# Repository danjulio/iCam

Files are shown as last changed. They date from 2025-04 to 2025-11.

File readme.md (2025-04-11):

## iCam and iCamMini thermal imaging cameras

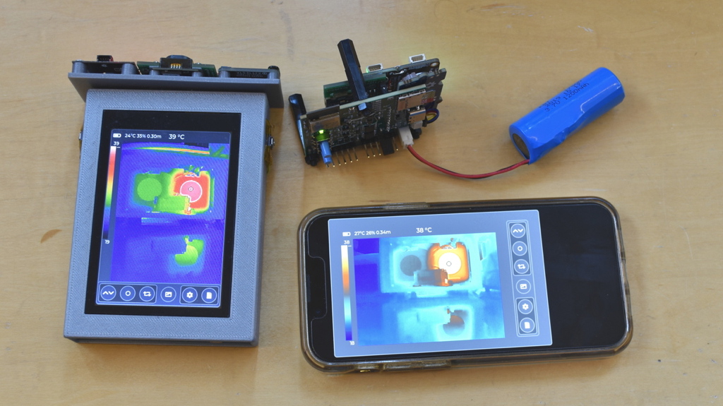
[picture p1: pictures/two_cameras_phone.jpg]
iCam and iCam Mini


This repository contains the design files for my Infiray Tiny1C-based thermal imaging cameras.  It also contains the documentation I have for the Tiny1C module from Infiray.

1. iCam - Handheld camera with local LCD touchscreen based on my ESP32 [gCore](https://github.com/danjulio/gCore) development board and the Tiny1C breakout board in this repository.
2. iCamMini - Portable camera with either web-based access or NTSC/PAL video output based on the iCamCntrl board in this repository and the Tiny1C breakout board.

The cameras share a common code base and feature set.

1. 256 x 192 pixel resolution.
2. Radiometric operation with adjustable emissivity.
3. Support for optional environmental (object distance, temperature and humidity) correction.
4. Adjustable high/low gain for extended temperature detection.
5. Support for calibration against a black body radiator.
6. Ten pseudo-color palettes.
7. Image storage and playback as jpg files on a Micro-SD card.
8. Selectable point and region markers.
9. Scene min/max temperature display.
10. Timelapse operation.
11. Battery-backed real-time clock for time stamping.
12. Rechargeable Li-Ion battery power source (or USB/external power).

tCam display is a local 16bpp 480x320 pixels capacitive touchscreen LCD.

tCamMini display is either via a Wi-Fi connected remote web browser (mobile aware) or analog video output (NTSC or PAL).  Analog video output may be used for long-distance operation, for example mounted on a UAV with video transmission capability.

### GUI
The main user interface screen is shown below.

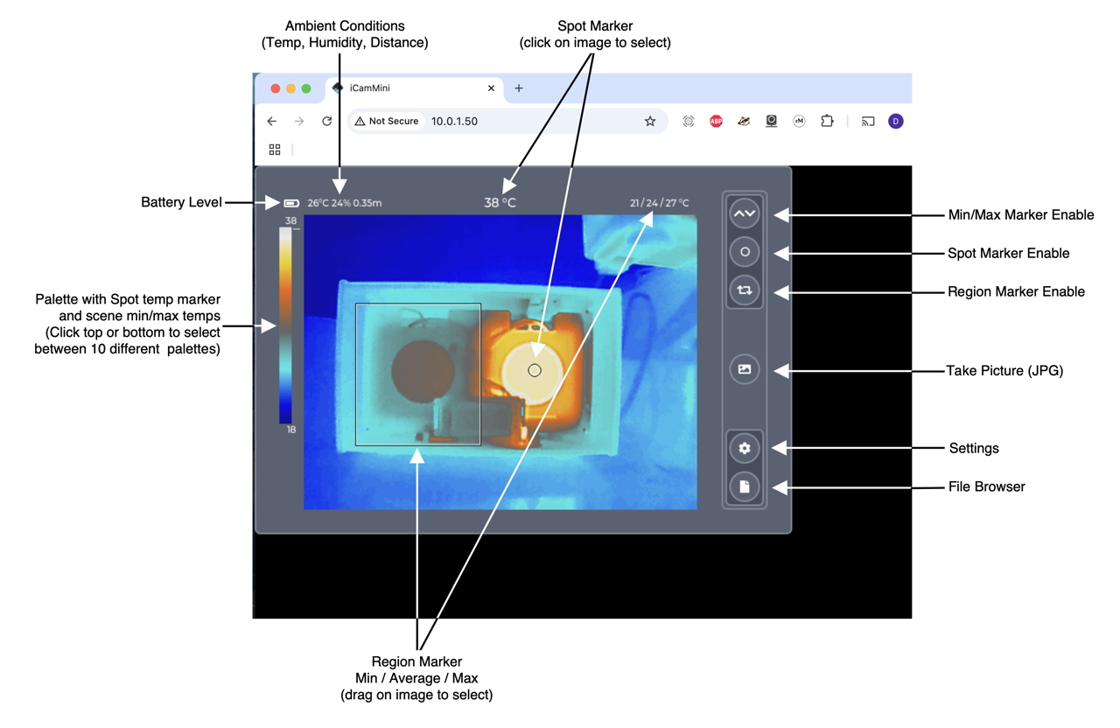
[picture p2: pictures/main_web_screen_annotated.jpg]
Main Screen


iCamMini also generates a simplified display when configured for analog video output.

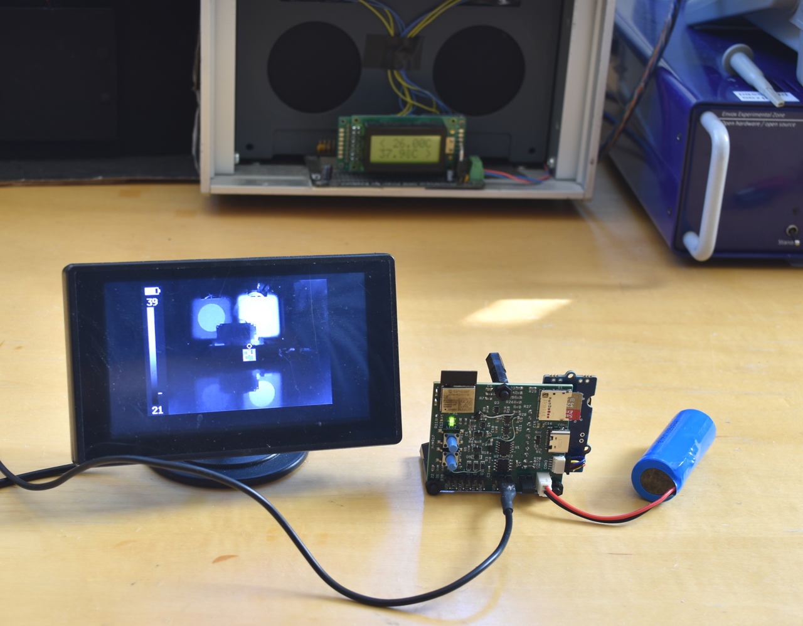
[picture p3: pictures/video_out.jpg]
Video output


Please see the readme in the iCamMini subdirectory for operation of the camera when configured for analog video output.

#### Settings
The settings screen configures the camera.  Most settings are identical on both cameras (for example, iCam does not have a Wi-Fi settings screen, iCamMini does not have a local brightness control).

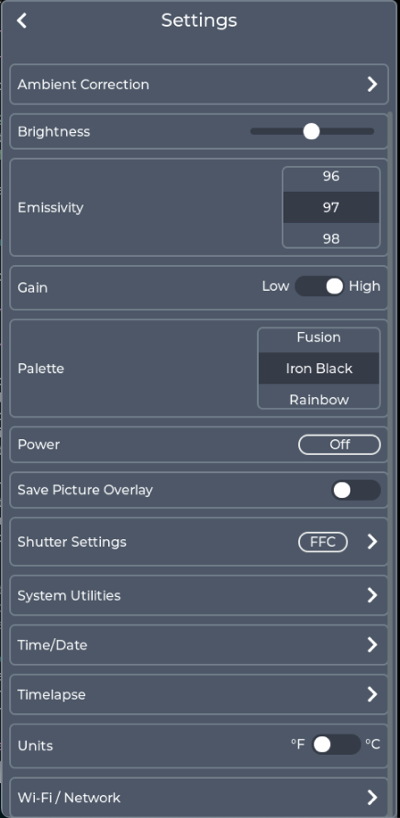
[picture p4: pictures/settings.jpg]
Settings Screen


##### Ambient Correction
Compensation factors for environmental conditions including ambient temperature and distance to object may be applied to improve radiometric temperature accuracy.  Currently humidity correction is not supported.

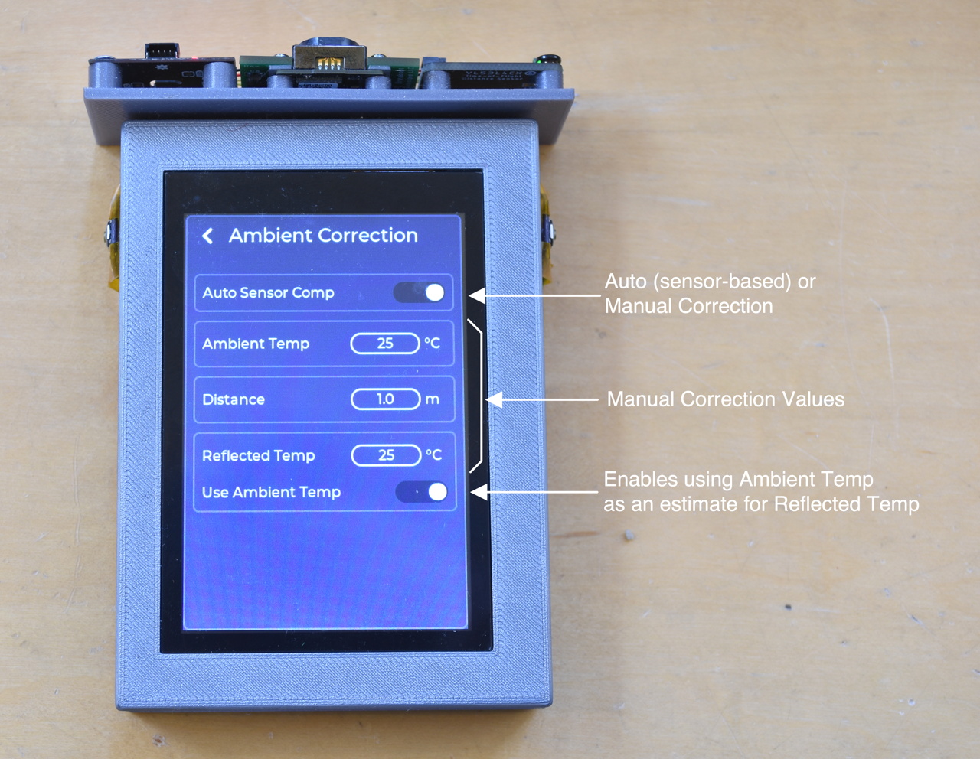
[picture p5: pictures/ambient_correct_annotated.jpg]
Ambient correction


These compensation factors may be configured manually through the Ambient Correction screen or automatically if [AHT20](https://www.adafruit.com/product/4566) Temperature/Humidity sensor and/or [VL53L4CX](https://www.adafruit.com/product/5425) 4M time-off-flight sensors are connected to the camera's I2C interface.  These sensors are automatically detected and applied if enabled in the Ambient Correction screen.

##### Tiny1C Calibration
One- or two-point calibration against a known black body radiator may be performed.

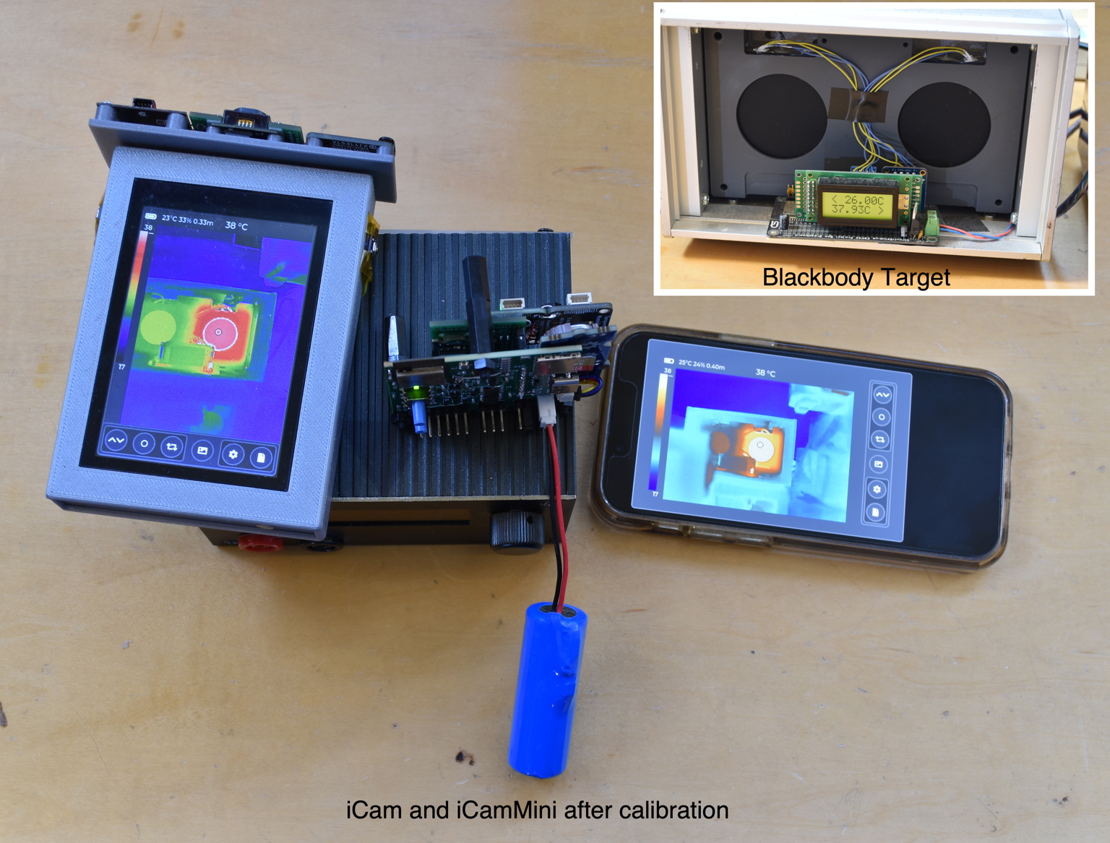
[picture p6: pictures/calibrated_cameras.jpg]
Calibration


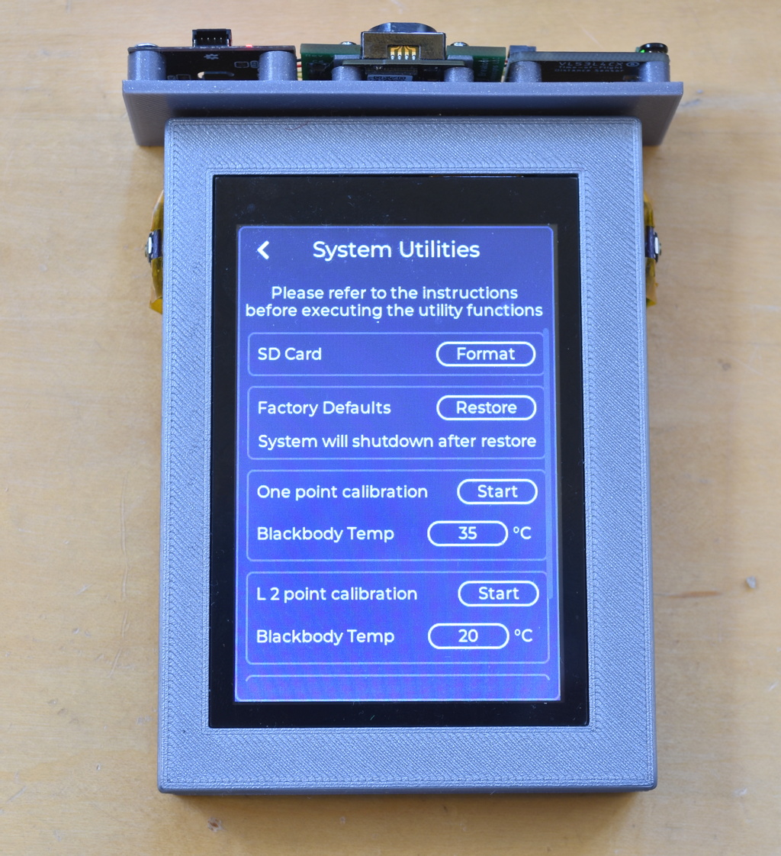
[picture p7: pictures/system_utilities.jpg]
Calibration Utilities


During calibration the camera should be 25 cm from a known black body radiator at a stable temperature.  The black body emissivity should be configured in the Emissivity Settings panel, and gain configured in the Gain Settings panel.

Two-point calibration is more accurate than one-point calibration but requires two widely separated black body temperatures (e.g. 293K and 393K in high gain and 373K and 673K in low gain).

Set the black body radiator temperature and then press ```Start```.  For two-point calibration, perform the ```L 2 point calibration``` and then perform the ```H 2 point calibration```.

##### Shutter configuration
Parameters related to automatic Flat Field Correction using the Tiny1C's built-in shutter are configured using the Shutter Settings screen.

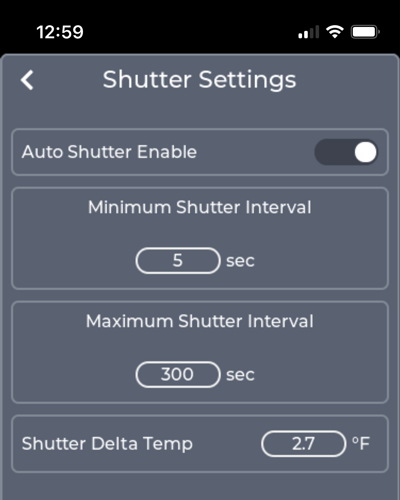
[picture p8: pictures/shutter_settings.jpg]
Shutter settings


##### Time / Date
The camera's clock is set through the Time/Date screen.  The clock is used to time stamp stored images.

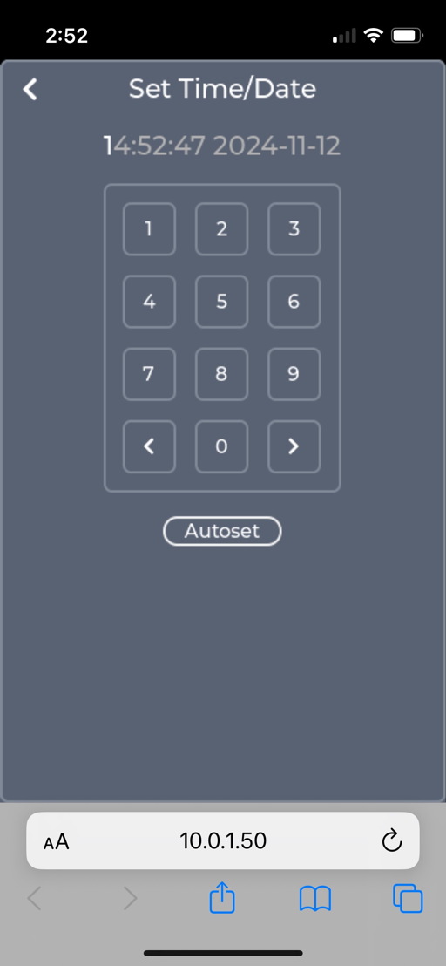
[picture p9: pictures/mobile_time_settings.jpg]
Time/Date screen
.

Pressing the ```Autoset``` button (iCamMini only) sets the camera to the host computer's current time.

##### Timelapse Operation
The camera may be configured to periodically take a picture.  The time between photographs and the number of photographs to take is configurable.

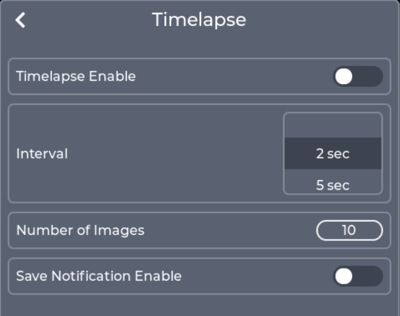
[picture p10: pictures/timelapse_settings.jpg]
Timelapse settings


Enabling Save Notifications will display the image name on the Main screen as it is taken.  The Main screen Take Picture button turns red while timelapse operation is in progress.

#### File Browser
Clicking the Take Picture button on the main screen (or pressing one of the buttons on iCamMini) stores the current image as a jpg file on the Micro-SD card if present.  The File Browser screen allows displaying and deleting image files.

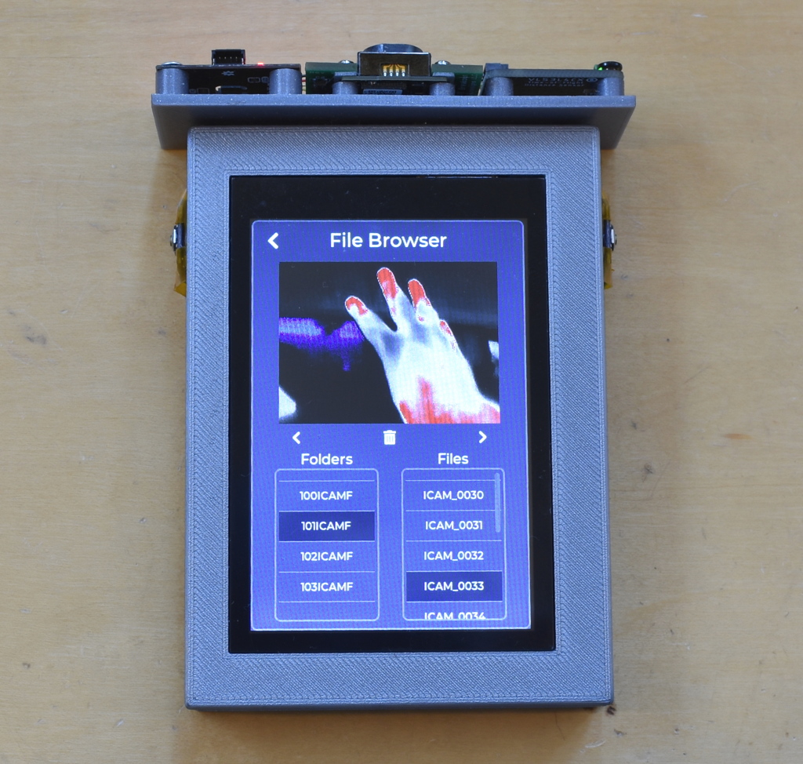
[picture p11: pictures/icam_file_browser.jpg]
File Browser


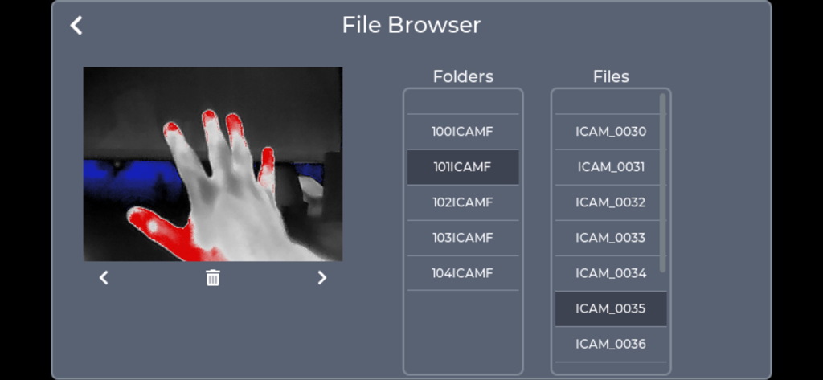
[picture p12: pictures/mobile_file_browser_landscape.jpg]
Landscape File Browser


Note the conversion process to a jpg image takes a few hundred milliseconds.

##### Image Files
Files are stored on the Micro-SD card using a DCIM compatible structure with 100 pictures per folder.

* Folder naming convention: ```nnnICAMF``` where ```nnn``` is a numeric sequence starting at 100.
* File naming convention: ```ICAM_nnnn.JPG``` where ```nnnn``` is a numeric sequence starting at 0001.

Files are 256x192 pixels in size.  An optional overlay of meta-data information can be included when the Save Picture Overlay is enable on the Main Settings screen.

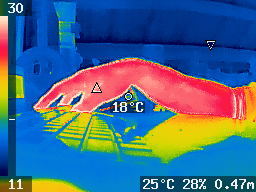
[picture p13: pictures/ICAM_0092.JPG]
Example jpg image


#### iCamMini Wi-Fi operation
When configured for Wi-Fi operation iCamMini is capable of acting as an Access Point (default) or a client connected to an existing Wi-Fi network.

It supports an mDNS responder that allows discovery from a web browser without having to know the IPV4 address.  The mDNS responder recognizes the local URL ```icam.local```.

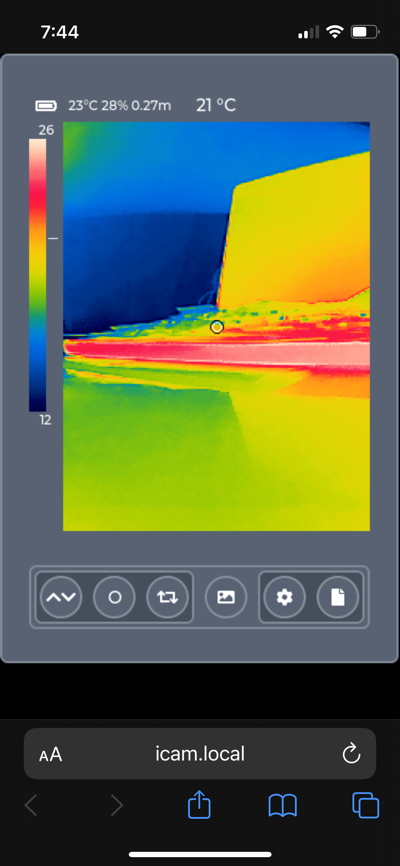
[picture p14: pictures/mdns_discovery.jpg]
mDNS Discovery


The Wi-Fi settings allow configuring the mode as well as an optional static IP address when configured into STA mode.

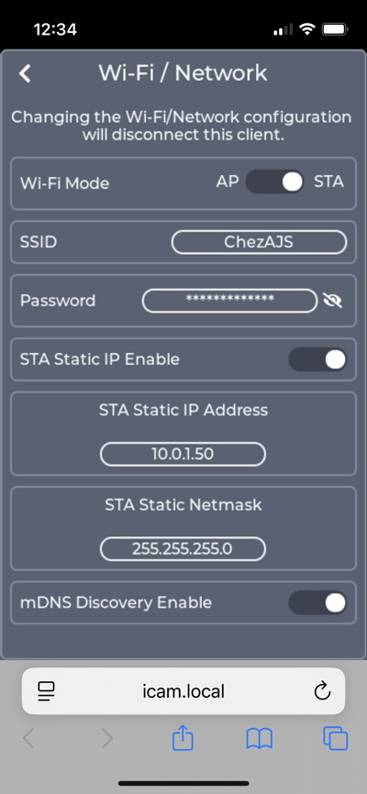
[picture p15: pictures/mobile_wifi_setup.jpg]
Wi-Fi settings


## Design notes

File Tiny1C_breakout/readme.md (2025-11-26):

## Tiny1C Breakout PCB
The Tiny1C Breakout PCB is used by both iCam and iCamMini.  It provides access to the Tiny1C VoSPI and I2C Command interfaces, as well as providing a low noise 5V analog power supply for the imager from a 3.3V input supply.  It provides a header interface for the [VL53L4CX](https://www.adafruit.com/product/5425) 4M time-off-flight sensor so that it can be close and aligned with the Tiny1C.  It also provides access to the Tiny1C diagnostic serial port and three of its GPIO signals (currently unused as far as I can tell).

The pinout basically follows the Flir Lepton breakout board sold by Group Gets.

This directory contains the gerber files as well as schematic documentation and a centroid file.  Parts can be found at my [Mouser shared BOM](https://www.mouser.com/Tools/Project/Share?AccessID=772c639990).

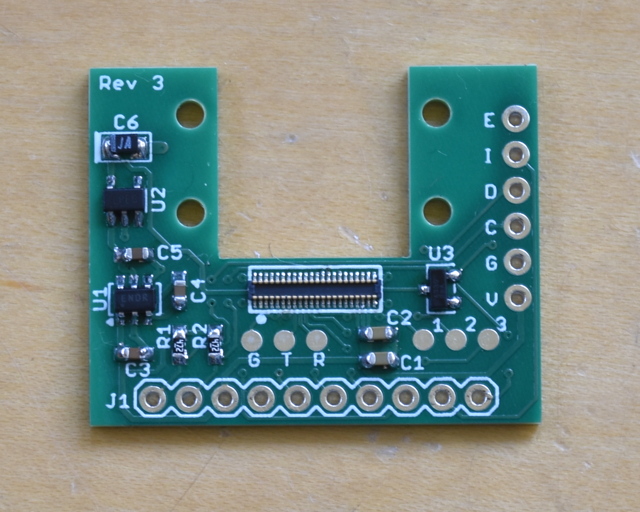
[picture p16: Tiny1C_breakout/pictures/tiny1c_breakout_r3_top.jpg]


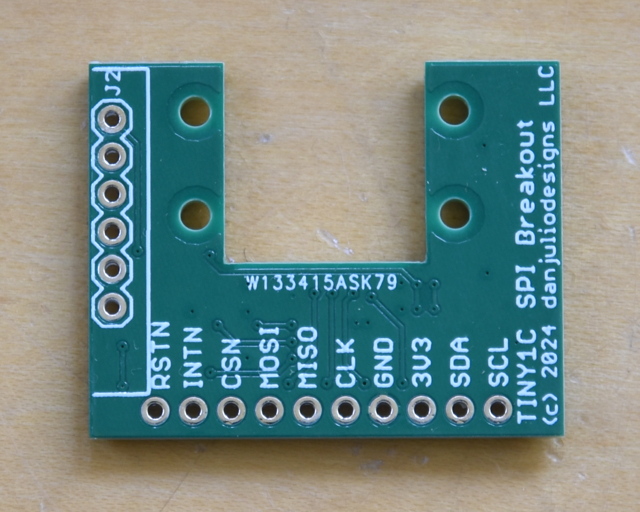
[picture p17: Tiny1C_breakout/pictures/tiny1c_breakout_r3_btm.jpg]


### Gerber Files

* 2 layer board
* 1.25" x 1.0"
* 1.6 mm thickness

| File | Description |
| --- | --- |
| tiny1c_breakout.GBL | Bottom Copper |
| tiny1c_breakout.GBO | Bottom Silkscreen |
| tiny1c_breakout.GBS | Bottom Soldermask |
| tiny1c_breakout.GML | Mill (outline) |
| tiny1c_breakout.GTL | Top Copper |
| tiny1c_breakout.GTO | Top Silkscreen |
| tiny1c_breakout.GTS | Top Soldermask |
| tiny1c_breakout.TXT | Drill |

### Board Connections

| Pin | Description |
| --- | --- |
| SCL | I2C clock signal to Tiny1C and VL53L4CX header |
| SDA | I2C data signal to Tiny1C and VL53L4CX header |
| 3V3 | 3.3V power supply for Tiny1C and VL53L4CX header.  Should be capable of 500 mA. |
| GND | Ground |
| MISO | SPI Data output from Tiny1C |
| MOSI | SPI Data input to Tiny1C |
| CSN | SPI active low chip select for Tiny1C |
| INTN | Active low interrupt from VL53L4CX header |
| RSTN | Active low reset input/output to Tiny1C and VL53L4CX.  See note below. |

The breakout board contains a power-on reset generator that pulls this signal low.  It may also be pulled low using an open-drain output on another controller.  The Tiny1C includes a built-in pull-up resistor on this line.

### Tiny1C Serial Port Connections

| Pad | Description |
| --- | --- |
| G | Ground |
| T | Tiny1C TX |
| R | Tiny1C RX |

### Tiny1C GPIO Port Connections

| Header Pin | Description |
| --- | --- |
| V | 3.3V Power input |
| G | Ground |
| C | I2C SCL |
| D | I2C SDA |
| I | GPIO Interrupt |
| E | Active low shutdown (used as reset input) |

## VL53L4CX Support

VL53L4CX Breakout board may be mounted on either side of the Tiny1C breakout board depending on your enclosure needs.  I used short pieces of cut wire soldered on both sides to hold the boards close together.  The I2C pull-up resistors may be left in place.

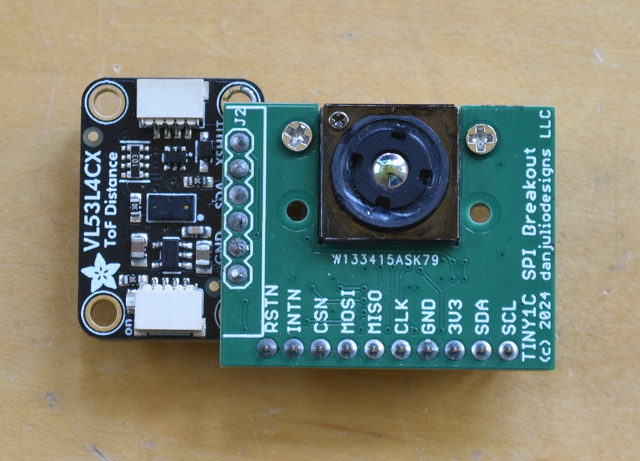
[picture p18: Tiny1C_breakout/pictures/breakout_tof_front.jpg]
Breakout with TOF Front


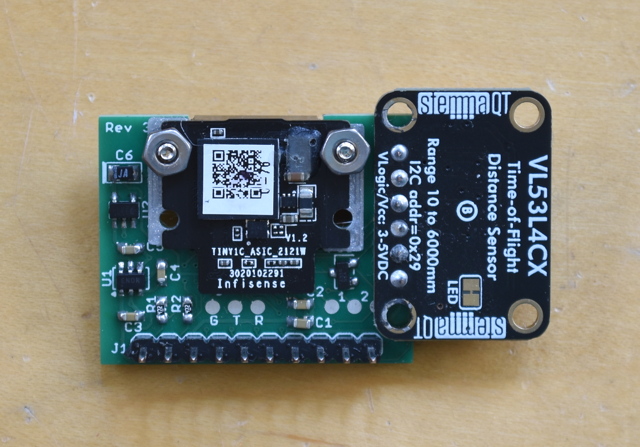
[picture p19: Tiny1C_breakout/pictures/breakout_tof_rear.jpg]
Breakout with TOF Rear


The Qwiic connector can be used to attach the AHT20 Temperature/Humidity sensor using a short Qwiic cable.  You want this sensor to be removed from any heat generating components, ideally only sampling the air around the camera.

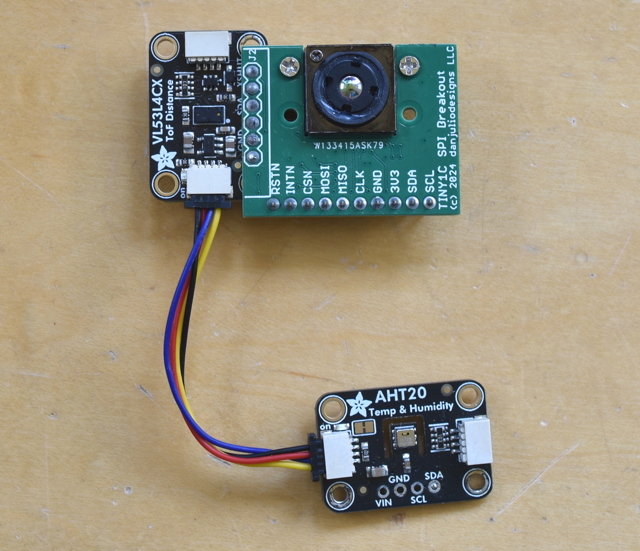
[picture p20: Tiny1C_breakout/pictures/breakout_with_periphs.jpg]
Breakout with TOF and Temp/Humidity Sensors


## Spacer and Tiny1C Mounting

The ```spacer``` subdirectory contains an OpenSCAD design (and resultant STL file) for a spacer that goes between the Tiny1C and the breakout board.  Two of these should be printed on a 3D printer.  Then a set of small screws can be used to secure the Tiny1C to the board.

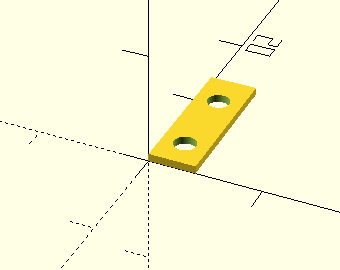
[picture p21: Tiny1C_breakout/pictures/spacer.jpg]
Spacer


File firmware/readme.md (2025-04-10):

## iCam Firmware
The firmware (```iCamCntrl```) in this directory runs on both iCam (gCore platform) and iCamMini (iCamCntrl platform) using the Espressif IDF.  It must be compiled separately for each platform.  Differences between the platforms are managed by conditionally compiled code.  A portion of this firmware for the iCamMini is also built using emscripten.  Much of the source code (the GUI code itself and the LVGL graphics library) are shared between the ESP32 and emscripten builds (see architecture diagrams below).

### Prerequisites
This firmware requires the following development environments.

1. [Espressif IDF v5.3](https://docs.espressif.com/projects/esp-idf/en/release-v5.3/esp32/index.html)
2. [Emscripten](https://emscripten.org/) - I build with SDK 3.1.64 but later versions should work too.  I also had to install SDL2 (on mac: ```brew install sdl2```).

I build using Mac OS X but this project should be buildable on Linux and Windows platforms as well, perhaps with some changes to shell commands.

### Building for iCam
Building firmware for iCam (gCore) is a straight-forward ESP32 IDF build.

#### Setup
1. Change to the ```firmware``` subdirectory
2. Source (run) the Espressif ```export.sh``` file and setup the ```IDF_PATH``` environment variable.
3. Source (run) the ```set_platform.sh``` script with the argument ```icam```.

``` ./set_platform.sh icam```

#### Build
Build the project using the Espressif tools

```idf.py build```

#### Program

##### Using IDF tools
Plug gCore into your computer and turn it on so that its serial port may be recognized and enumerated by the operating system.  Make a note of the serial port name (for example on OS X it is ```/dev/cu.SLAB_USBtoUART```).

```idf.py -p [SERIAL PORT] -b 921600 flash```

where SERIAL PORT is the serial port associated with gCore.

##### Using the Windows-based Espressif programming tool
The precompiled firmware files found in the ```iCam/precompiled``` directory may be downloaded without having to build them using the Windows-based Espressif Flash Download tool that can be found [here](https://www.espressif.com/en/support/download/other-tools).

The various files are loaded in flash memory as follows.

| Binary File | Flash Location |
| --- | --- |
| bootloader.bin | 0x1000 |
| iCamCntrl.bin | 0x10000 |
| partion-table.bin | 0x8000 |
| ota\_data\_initial.bin | 0xd000 |
| storage.bin | 0xb10000 |

#### Serial Diagnostic data

The firmware logs various events to gCore's USB serial port.  This may be viewed by connecting the Espressif serial monitor as shown below.

```idf.py -p [SERIAL PORT] monitor```

### Building for iCamMini
Building firmware for iCamMini (iCamCntrl hardware) is a two-step process.

1. Build the HTML page that the camera sends to the browser using emscripten, compress it and copy it to the Espressif project.
2. Build the Espressif project and load the combined binary into the camera.

#### Emscripten build
Build the emscripten portion before building and programming the ESP32 portion.  This only needs to be done initially or when any part of the emscripten source changes.

1. One time only: change directory to the ```emscripten``` subdirectory and create a ```build``` directory there.
2. Change directory to ```emscripten/build``` subdirectory in a shell dedicated to building the emscripten portion of the firmware.
3. Source the emscripten ```emsdk_env.sh``` file to configure the emscripten environment.
4. First time and only when you add new source files to the emscripten build: run the command ```emcmake cmake ..```
5. Build the emscripten code: ```emmake make -j4```
6. Compress the resultant html file: ```gzip index.html```
7. Move the compressed file into the ESP32 build area: ```mv index.html.gz ../../components/esp32_web```

Steps 5-7 are performed each time a change is made to the existing firmware.  Perform step 4 when the file structure changes.

#### ESP32 build
I build the ESP32 portion using another shell window.  It is done after making any emscripten changes.  The compressed HTML file must be built and stored in the ```components/esp32_web``` subdirectory.

1. Change directory to the ```firmware``` subdirectory.
2. Configure the project to build for iCamMini: ``` ./set_platform.sh icam_mini```
3. Build the project using the Espressif tools:```idf.py build```

#### Program

##### Using IDF tools
Plug the iCamCntrl board into your computer and press and hold the power button so that its serial port may be recognized and enumerated by the operating system.  Make a note of the serial port name (for example on OS X it is something like ```/dev/cu.wchusbserial110```).

```idf.py -p [SERIAL PORT] -b 921600 flash```

where SERIAL PORT is the serial port associated with iCamCntrl.

##### Note about iCamCntrl power
You must continue to hold the power button on during programming because the hardware implements a soft power control in firmware.  When firmware is not running then it cannot drive a GPIO output that holds power enabled.  You may release the power button after programming is finished.

When programming is finished then press the power button and hold until the status LED lights.   At this point the firmware is driving the power hold signal.

##### Using the Windows-based Espressif programming tool
The precompiled firmware files found in the ```iCamMini/precompiled``` directory may be downloaded without having to build them using the Windows-based Espressif Flash Download tool that can be found [here](https://www.espressif.com/en/support/download/other-tools).

The various files are loaded in flash memory as follows.

| Binary File | Flash Location |
| --- | --- |
| bootloader.bin | 0x1000 |
| iCamCntrl.bin | 0x10000 |
| partion-table.bin | 0x8000 |
| ota\_data\_initial.bin | 0xd000 |
| storage.bin | 0x710000 |

#### Serial Diagnostic data

The firmware logs various events to iCamCntrl's USB serial port.  This may be viewed by connecting the Espressif serial monitor as shown below.

```idf.py -p [SERIAL PORT] monitor```

### Firmware Architecture
Most of the code is shared between both platforms.  Aside from platform-specific functionality (and analog video output) the main difference is in where the LVGL-based GUI runs.  In order to support this architecture the GUI display is separated from the camera application code by a SET/GET/RESPONSE command interface.  These commands are used to get and update state on both sides of the interface.  In iCam they become direct function calls between domains and in iCamMini they are serialized and deserialized across a websocket interface.

![iCam Firmware Architecture](pictures/icam_fw_arch.jpg)

![iCamMini Firmware Architecture](pictures/icam_mini_fw_arch.jpg)

The command interface is not used when iCamMini is configured for video output.

![iCamMini Firmware Architecture with Video output](pictures/icam_mini_vid_fw_arch.jpg)

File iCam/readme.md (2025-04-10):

## iCam Prototype
I call this a prototype because I'd like to design a better enclosure but the camera itself is functional.

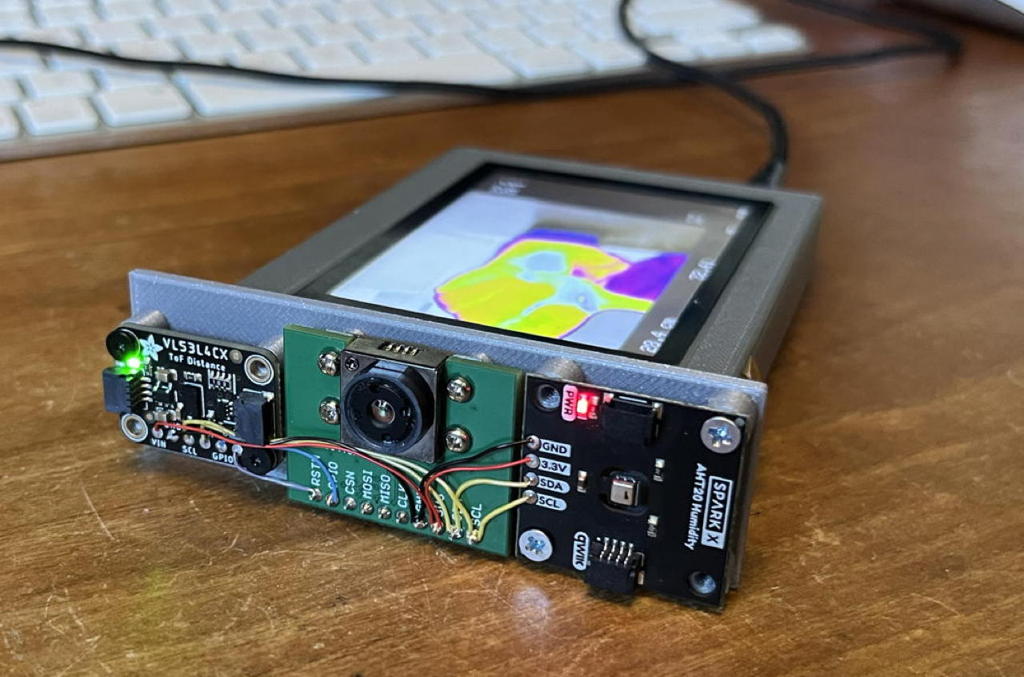
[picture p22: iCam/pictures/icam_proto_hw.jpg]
iCam Prototype Hardware


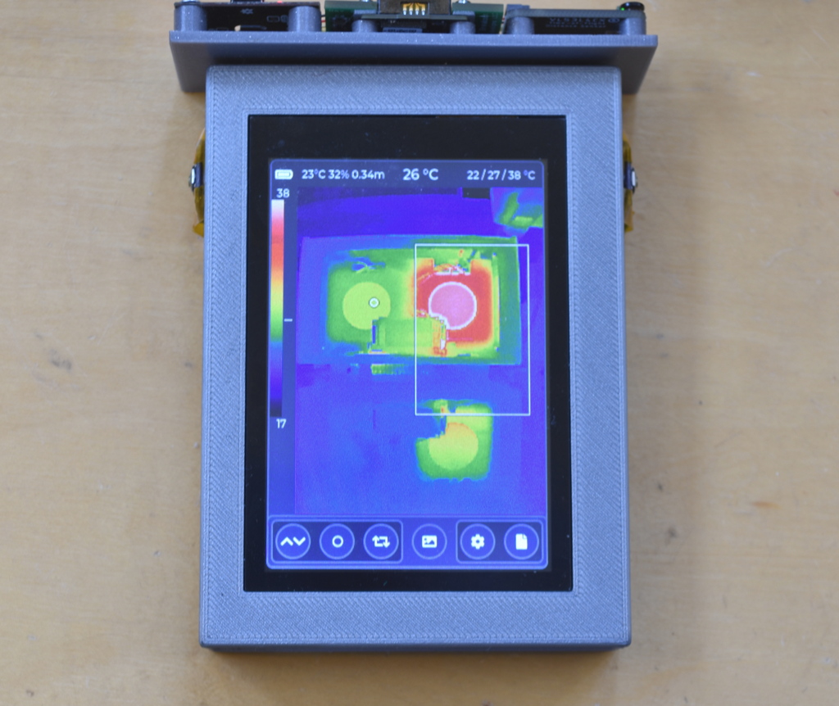
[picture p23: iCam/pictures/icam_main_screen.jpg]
iCam Main Screen


Instructions for programming the precompiled firmware may be found in the ```firmware``` directory.

### Hardware Architecture
The hardware consists of a [gCore](https://github.com/danjulio/gCore) development board with Tiny1C, VL53L4CX and AHT20 breakout boards.

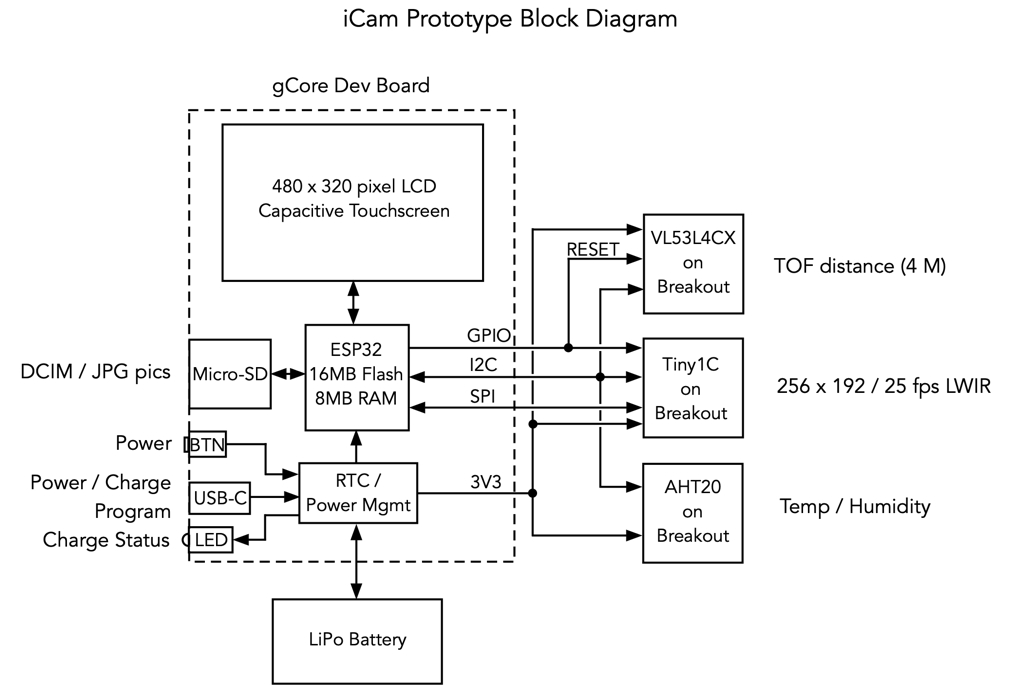
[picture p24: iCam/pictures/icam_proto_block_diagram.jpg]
iCam Hardware Architecture


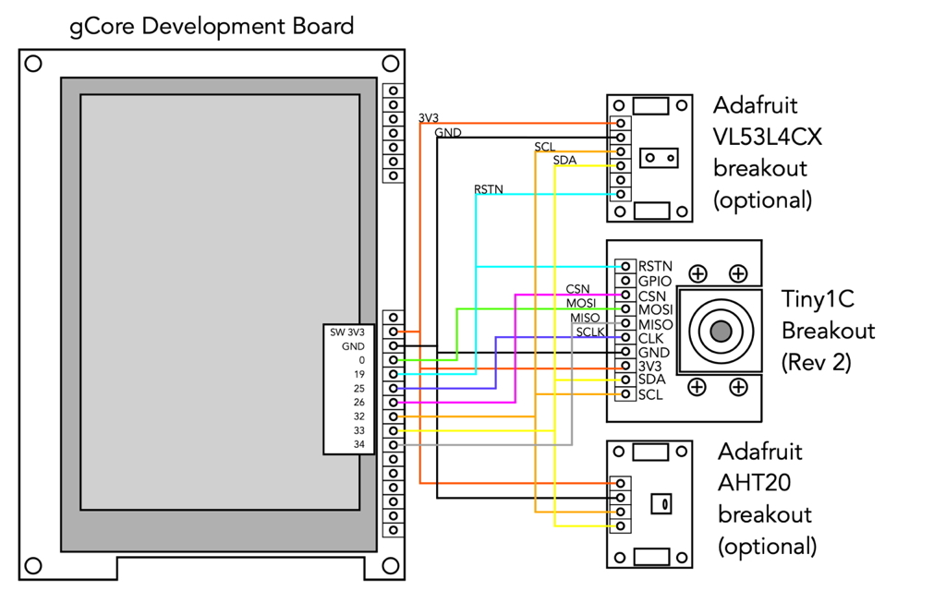
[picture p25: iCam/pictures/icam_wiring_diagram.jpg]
iCam Hardware Diagram


Note that the reset signal goes to both the Tiny1C and VL53L4CX boards.  This is necessary as the firmware resets the hardware before configuring it and the VL53L4CX will malfunction if you attempt to reconfigure it after it has been running without a reset.

### Prototype Enclosure
The enclosure consists of two 3D printed parts, the gCore enclosure (which you can find at the gCore repo) and a sensor mount that's double-sticky tape attached to the gCore enclosure.

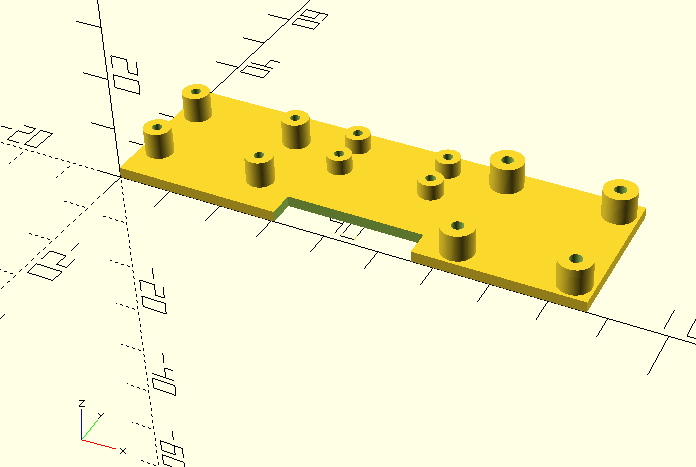
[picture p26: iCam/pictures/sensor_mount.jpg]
Sensor Mount render


The OpenSCAD design and resultant STL file for the sensor mount may be found in the ```sensor_mount``` subdirectory.  Note that for this prototype I used a Sparkfun AHT20 breakout board so the mount will have to be redesigned to use the Adafruit version (just copy the VL53L4CX portion over).

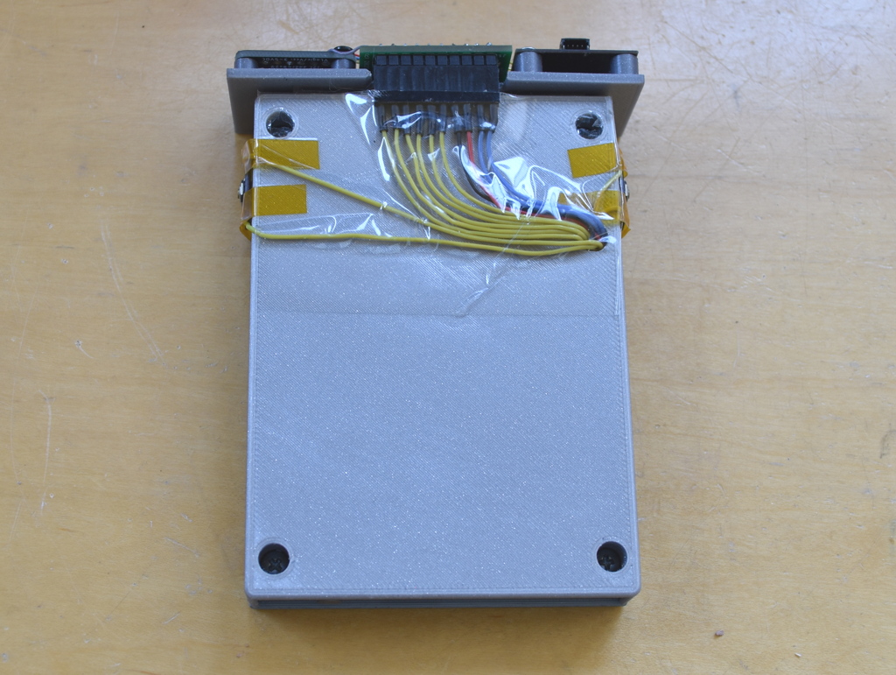
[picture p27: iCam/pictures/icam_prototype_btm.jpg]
Sensor Mount attachment


Note that I wired two buttons on this prototype but they are currently unused by the firmware.

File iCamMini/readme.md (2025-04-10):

## iCamMini
iCamMini is a small, battery powered, thermal imaging camera with two different output modes.  It can communicate with a remote web browser over Wi-Fi or it can output an analog video output with either NTSC or PAL timing.

It is comprised of a iCamCntrl main board and Tiny1C Breakout board.  Optionally a VL53L4CX and/or AHT20 breakout board may be added sensing environmental conditions to improve the radiometric accuracy of the camera.

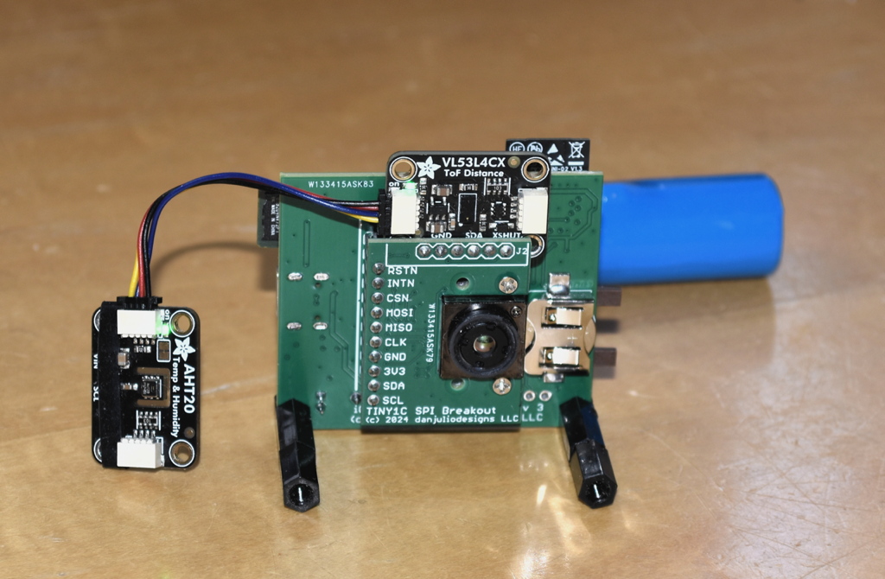
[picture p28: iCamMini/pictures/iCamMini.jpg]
iCamMini hardware


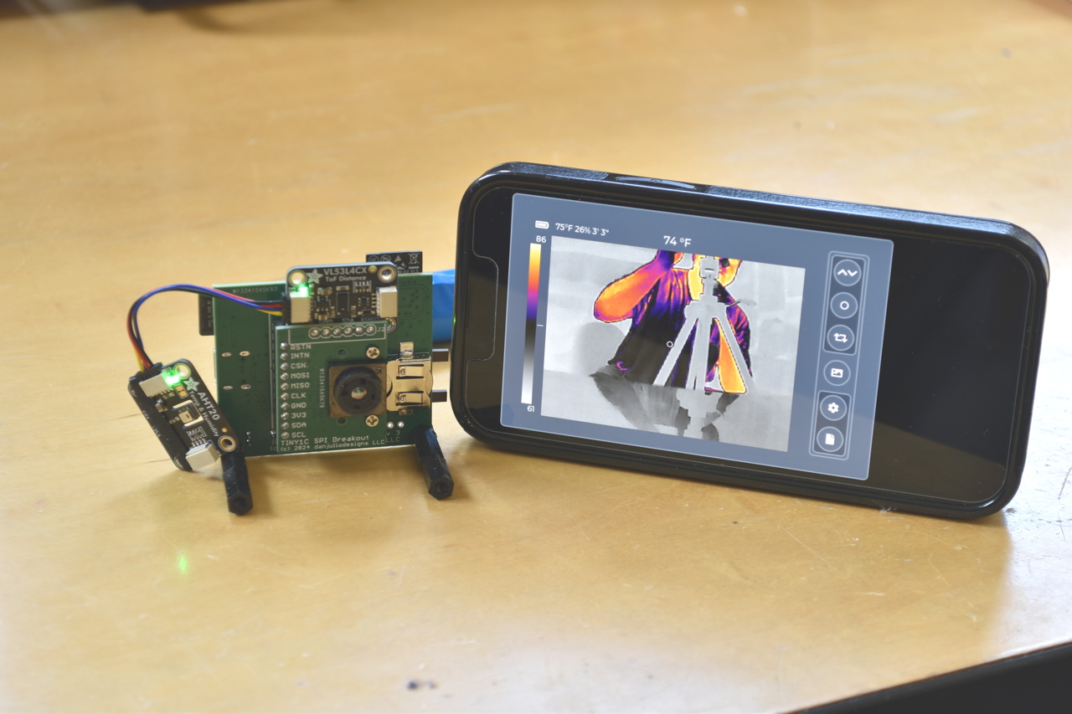
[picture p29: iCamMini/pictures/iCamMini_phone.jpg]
iCamMini with iPhone


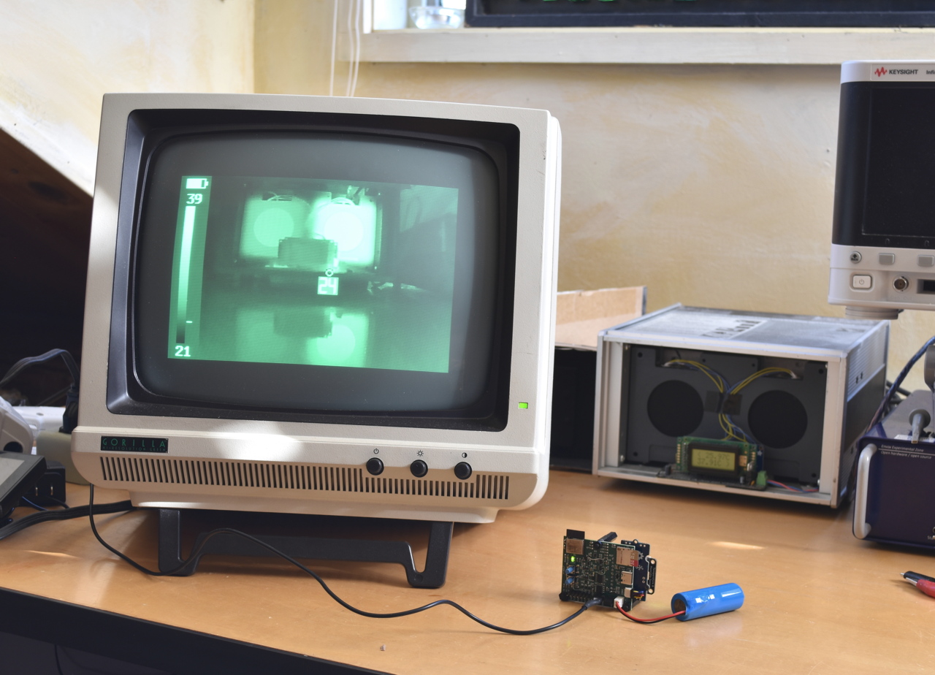
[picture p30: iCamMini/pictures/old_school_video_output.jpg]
iCamMini with old-school analog monitor


The iCamCntrl hardware is documented in the ```iCamCntrl_board``` subdirectory.

### Battery
iCamMini can operate with or without a 3.7V Li-Ion battery.  The Li-Ion battery charger provides up to 500 mA of charge current.  The battery should be 2500 mA or less.  The camera typically operates between 200-300 mA (with bursts when the Tiny1C performs a flat-field correction).

#### RTC Battery
The real-time clock is kept powered when the camera is off using a CR1225 3V Lithium coin cell.

### Mode Selection
The output mode is selected at boot using the MODE jumper.  It cannot be changed once the camera is running.

| Jumper Position | Mode |
| --- | --- |
| In | Wi-Fi/Web Browser mode |
| Out | Analog output mode |

### Board Controls
The board contains two push buttons (PB1, PB2) and two LEDs (LED1, LED2).  LED1 is a blue LED.  LED2 is a red/green LED capable of three colors (Red, Green, Orange/Yello).

PB1 is always used to turn the board on or off.  Hold PB1 pressed until LED2 lights.  Then you can release it.  To turn the camera off, press and hold the button for more than three seconds (long-press).  LED2 will turn off then you can release the button.

LED1 is lit when the battery is charging.

LED2 is initially red.  It switches to another, mode-dependent color, when the camera has successfully booted (passed all self-tests and configured all peripherals).  It will blink red if any errors are detected, followed by a short period where it is off.  The number of blinks indicate the failing function. 

| Blinks | Fault Type |
| --- | --- |
| 1 | ESP32 core initialization failed |
| 2 | ESP32 peripheral initialization failed |
| 3 | ESP32 static memory allocation failed |
| 4 | Tiny1C CCI initialization failed |
| 5 | Tiny1C VoSPI communication failed |
| 6 | Tiny1C video stream sync failed |
| 7 | Video output initialization failed |
| 8 | Web Server failure |

LED2 also briefly blinks whenever a picture is taken and stored on the Micro-SD card.

The remaining functionality of the buttons and LED2 depends on what output mode the camera is running. 

### Wi-Fi / Web Browser Mode
LED2 indicates connectivity mode.

| LED2 | Meaning |
| --- | --- |
| Fast Blinking Orange | Wi-Fi Reset |
| Slow Blinking Orange | AP Mode: No device connected |
| | STA Mode: Not connected to AP |
| Solid Orange | AP Mode: Device connected |
| | STA Mode: Connected to AP |
| Solid Green | Client connected (web browser connected) |

#### Button 1

| Press Type | Function |
| --- | --- |
| Short Press | Take Picture when not in settings mode.  Select next parameter value when in settings mode. |
| Long Press | Turn camera off |

#### Button 2

| Press Type | Function |
| --- | --- |
| Short Press | No function. |
| Long Press | Wifi Reset back to default AP settings. |

### Video Output Mode

LED2 turns from red to green to indicate the camera has booted successfully (passed all self-tests and configured all peripherals).

#### Button 1

| Press Type | Function |
| --- | --- |
| Short Press | Take Picture when not in settings mode.  Select next parameter value when in settings mode. |
| Long Press | Turn camera off |

#### Button 2

| Press Type | Function |
| --- | --- |
| Short Press | No function when not in settings mode.  Select next parameter when in settings mode. |
| Long Press | Enter/Exit settings mode. |

#### Video Output Mode Settings

Camera parameters are changed in video output mode by entering settings mode (Button 2 long press).  Short press Button 1 to select among parameter values.  Short press Button 2 to select next parameter.  Long press Button 2 to exit settings mode.

The current parameter and value is displayed on the video output screen.

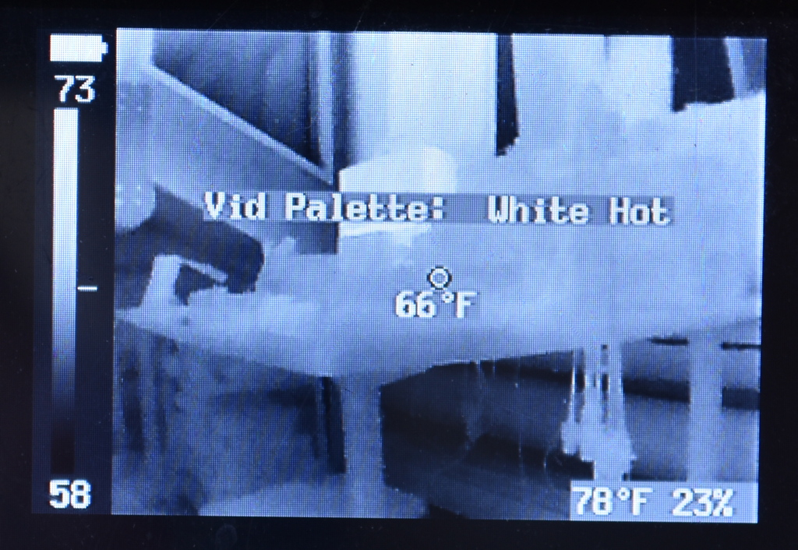
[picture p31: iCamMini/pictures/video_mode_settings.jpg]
Video Mode Settings display


| Parameter | Description |
| --- | --- |
| Vid Palette | Selects between White-hot and Black-hot video output palettes. |
| Spot | Sets Spot (centered) temperature display on or off. |
| Min/Max Markers | Sets minimum and maximum temperature markers on or off. |
| FFC | Triggers a flat-field correction in the Tiny1C. |
| Brightness | Sets the Tiny1C video pipeline output brightness. |
| Emissivity | Sets the Tiny1C Emissivity between a set of pre-defined values. |
| Gain | Sets the Tiny1C to Low or High gain. |
| Env Correct | Sets environmental correction on or off.  Note that use of sensors and/or pre-defined values is configured via the control panel in Wi-Fi mode. |  
| Save Overlay | Sets the metadata information display on saved images on or off. |
| Save Palette | Selects one of the ten pseudo-color palettes to use when saving images. |
| Timelapse | Sets timelapse mode on or off.  When on, pressing the Take Picture button starts the timelapse sequence. |
| Timelapse Interval | Sets the interval between timelapse photos from a predefined set of intervals. |
| Timelapse Images | Sets the number of timelapse photos to take from a predefined set of pictures. |
| Tmelapse Notify | Sets the notification of each timelapse picture taken on the video output screen on or off. |
| Units | Selects between Metric (°C) and Imperial (°F) display units. |
| Video | Selects between NTSC and PAL video timing. |

### Video Output
Video output uses the ESP32 8-bit DAC so it is not a perfect display.  DAC codes are allocated as follows.

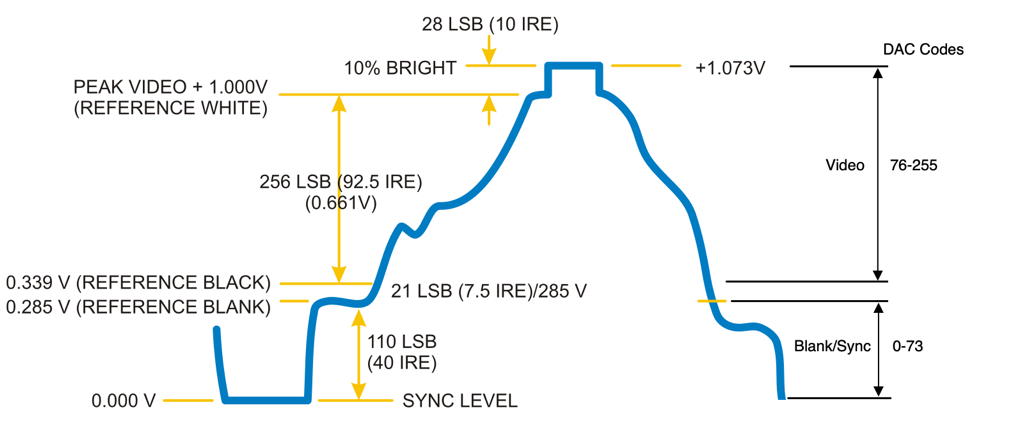
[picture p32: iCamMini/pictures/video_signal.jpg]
Video DAC waveform


The DAC also exhibits some output switch noise that manifests in a sparkling noise overlaying the image.

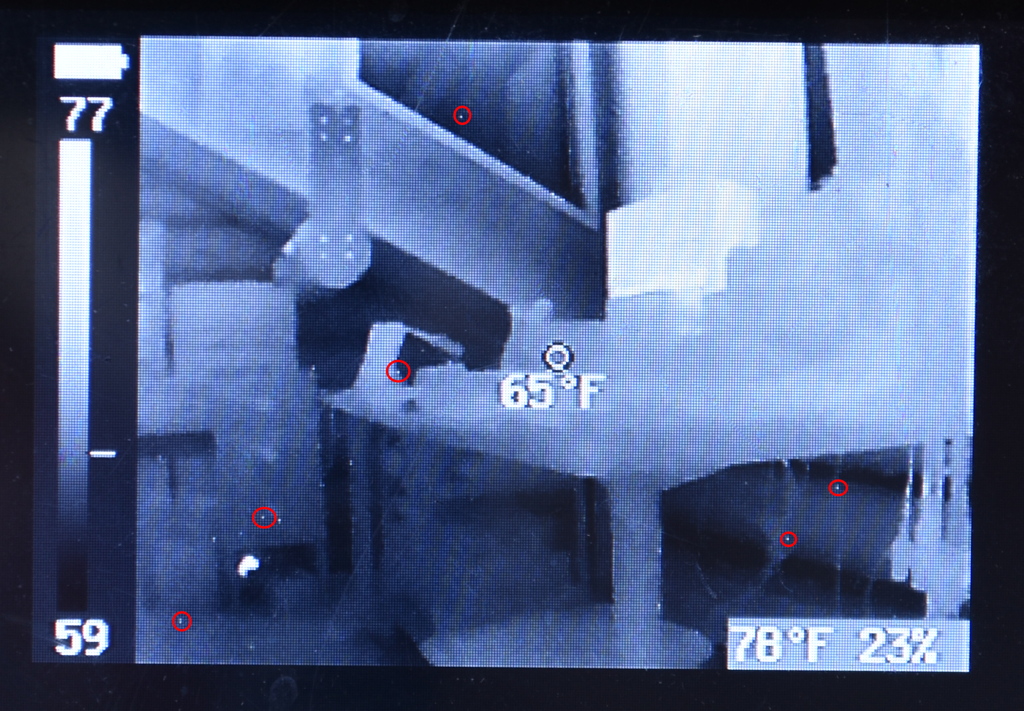
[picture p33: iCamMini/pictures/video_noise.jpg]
Video DAC noise


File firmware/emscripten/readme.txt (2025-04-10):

get_em              [runs [PATH]/emscripten/emsdk/emsdk_env.sh]
cd build
emcmake cmake ..    [first time or when files are added or have been deleted]
emmake make -j4
gzip index.html
mv index.html.gz ../../components/esp32_web

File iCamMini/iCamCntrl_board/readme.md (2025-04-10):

## iCamCntrl PCB
The iCamCntrl PCB forms the core of iCamMini.  It contains the following main subsystems.

1. ESP32-PICO-MINI-02 with 8 MB Flash and 2 MB PSRAM.
2. CH340K based USB UART and USB-C connector for programming and diagnostic output.
3. TP4056 Li-Ion battery charger.
4. Soft power control switching circuitry.
5. Micro-SD card (SPI Interface).
6. PCF85063ATT battery-backed RTC.
7. OPA361 video amplifier and driver, 75 ohm video output.
8. Serial interface with flow control (currently unused).
9. Separate 3.3V power supply for Tiny1C breakout for added noise reduction when generating the Tiny1C 5V analog supply.

It has a flexible power input sources.

1. USB Power (charges battery).
2. 3.7 Volt Li-Ion battery with Sparkfun/Adafruit connector.
3. 5V in on video port (for example may be used for a 3-wire connection on a drone).
4. 5V in on serial port (for example may be used when connected to a UAV controller).

All inputs are diode-isolated.

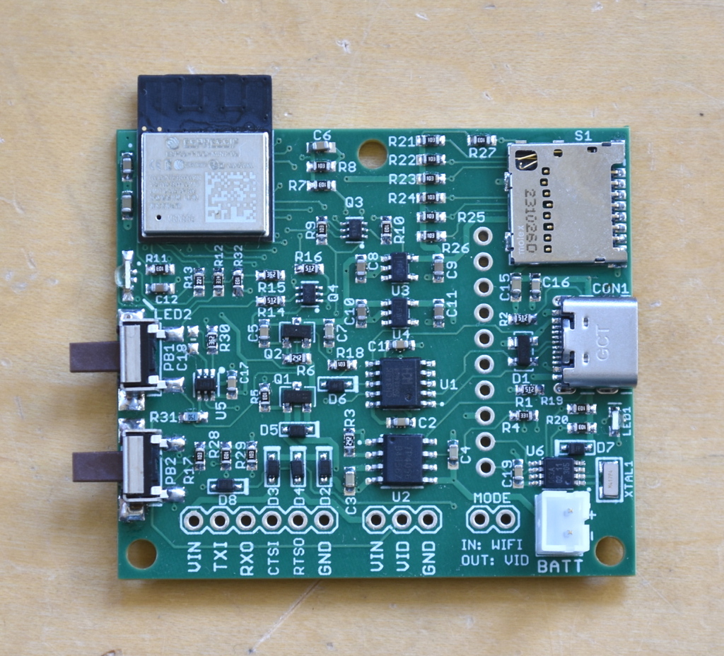
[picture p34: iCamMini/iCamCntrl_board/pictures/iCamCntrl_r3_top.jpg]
iCamCntrl Top


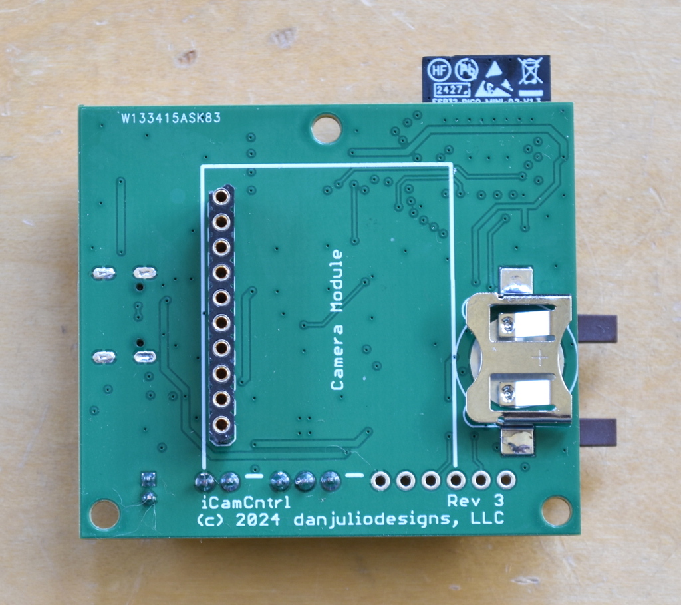
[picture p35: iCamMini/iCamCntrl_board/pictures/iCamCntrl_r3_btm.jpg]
iCamCntrl Bottom


### PCB
* 4 layer board
* 2.0" x 1.75"
* 1.6 mm thickness

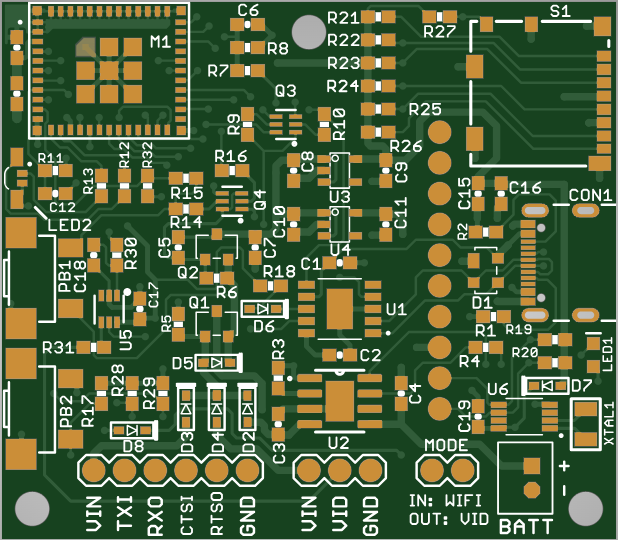
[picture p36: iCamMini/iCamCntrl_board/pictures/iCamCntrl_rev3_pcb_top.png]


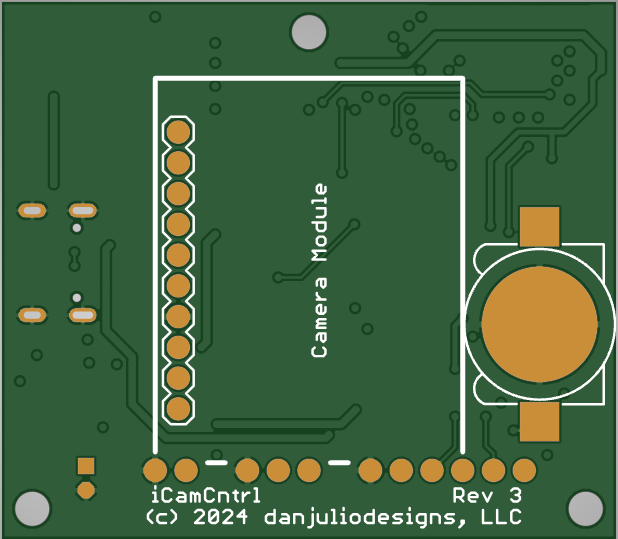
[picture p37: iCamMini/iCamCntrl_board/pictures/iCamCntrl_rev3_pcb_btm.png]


### Gerber Files

| File | Description |
| --- | --- |
| iCamCntrl.GBL | Bottom Copper (layer 4) |
| iCamCntrl.GBO | Bottom Silkscreen |
| iCamCntrl.GBS | Bottom Soldermask |
| iCamCntrl.GL3 | Internal Copper (layer 3) |
| iCamCntrl.GL2 | Internal Copper (layer 2) |
| iCamCntrl.GML | Mill (outline) |
| iCamCntrl.GTL | Top Copper (layer 1) |
| iCamCntrl.GTO | Top Silkscreen |
| iCamCntrl.GTS | Top Soldermask |
| iCamCntrl.TXT | Drill |

### Soft Power Control
Soft Power Control is implemented using a high-side P-Channel MOSFET transistor.  It is enabled when PB1 is pressed.  Then firmware running on the ESP32 must drive the PWR\_HLD signal before the button is released to hold power.  This allows the ESP32 to shut power off by de-asserting PWR\_HLD.  The firmware lights the LED immediately after asserting PWR_HLD at boot as a prompt to the user that they can release the button.  However releasing the button before the ESP32 will result in the board powering down.

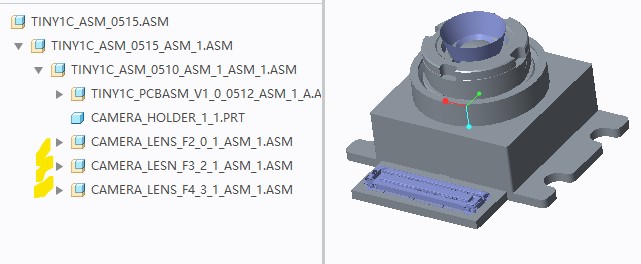
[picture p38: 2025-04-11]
Tiny1C_documentation/mechanical/3D_asm_notes.jpg

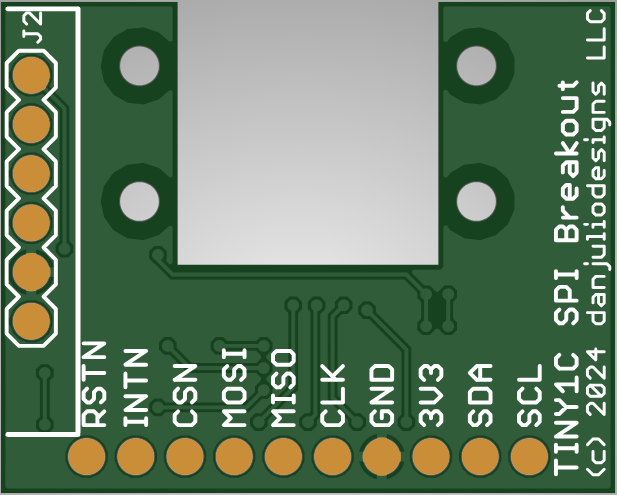
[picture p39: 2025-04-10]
Tiny1C_breakout/pictures/Tiny1C_breakout_rev3_pcb_btm.png

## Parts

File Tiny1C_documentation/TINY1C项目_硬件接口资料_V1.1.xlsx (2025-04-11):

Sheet: Information
TINY1C Module Hardware Interface Brief Introduce
No. | 内容 | Information | Notes
1 | PCBA PN | 2030108356 | PCBA Associated
2 | PCBA Description | 硬质PCBA；TINY1C_ASIC_BOARD_V1_2_1_PCBA
3 | Designer | 姚鹏
4 | Confimed Time | 20211021
5 | Functional Block Diagram | Functional Block Diagram'!A1
6 | Pin Descriptions | Pin Descriptions'!A1
7 | Electrical Specifications | Electrical Specifications'!A1
8 | Power Sequence | Power Sequence'!A1
9 | Demo Descriptions | Demo Descriptions'!A1 | 需要与原理图、PCB保持一致
10 | Notes | Notes!A1
Update Content
No. | Versions | Update | Designer | Time
1 | V1.0 | first edition | 姚鹏 | 20211106
2
3
4
5
6
7
8

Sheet: Pin Descriptions
Connector：WP7B-S040VA1-R8000;JAE;0.4mm pitch;40pin;Receptacle | No. | NAME | VOLTAGE | Fonction 1 |  |  |  | Fonction 2 |  |  |  | Notes
 |  |  |  | I/O Type | Group | Description | Recommended Connection | I/O Type | Group | Description | Recommended Connection
 | 1 | VO1_DATA10 | 3.3V | O_PD | DVP | Video Output DVP Signal:DATA2 | Connect to DVP interface:DATA2
 | 2 | VO1_DATA09 | 3.3V | O_PD | DVP | Video Output DVP Signal:DATA1 | Connect to DVP interface:DATA1
 | 3 | VO1_DATA14 | 3.3V | O_PD | DVP | Video Output DVP Signal:DATA6 | Connect to DVP interface:DATA6 | I_PD | SPI | Video Output SPI Signal:CS | Connect to SPI interface:CS
 | 4 | VO1_DATA13 | 3.3V | O_PD | DVP | Video Output DVP Signal:DATA5 | Connect to DVP interface:DATA5 | I_PD | SPI | Video Output SPI Signal:MOSI | Connect to SPI interface:MOSI
 | 5 | VO1_DATA15 | 3.3V | O_PD | DVP | Video Output DVP Signal:DATA7 | Connect to DVP interface:DATA7 | I_PD | SPI | Video Output SPI Signal:CLK | Connect to SPI interface:CLK
 | 6 | VO1_DATA11 | 3.3V | O_PD | DVP | Video Output DVP Signal:DATA3 | Connect to DVP interface:DATA3
 | 7 | VO1_DATA12 | 3.3V | O_PD | DVP | Video Output DVP Signal:DATA4 | Connect to DVP interface:DATA4 | O_PD | SPI | Video Output SPI Signal:MISO | Connect to SPI interface:MISO
 | 8 | VO1_PIXCLK | 3.3V | O_PD | DVP | Video Output DVP Signal:CLK | Connect to DVP interface:CLK
 | 9 | VO1_DATA08 | 3.3V | O_PD | DVP | Video Output DVP Signal:DATA0 | Connect to DVP interface:DATA0
 | 10 | VO1_VSYNC | 3.3V | O_PD | DVP | Video Output DVP Signal:VSYNC | Connect to DVP interface:VSYNC
 | 11 | VO1_HSYNC | 3.3V | O_PD | DVP | Video Output DVP Signal:HSYNC | Connect to DVP interface:HSYNC
 | 12 | IIC_SLV_SDA | 3.3V | I_PU/O | IIC | IIC Slave:DATA | Connect to IIC Master:DATA; An external Pullup resistor to VDD33 needed; (4.7K for recommend)
 | 13 | IIC_SLV_SCL | 3.3V | I_PU | IIC | IIC Slave:CLK | Connect to IIC Master:CLK; An external Pullup resistor to VDD33 needed; (4.7K for recommend)
 | 14 | GND |  | G | GND | GND | Connect to GND
 | 15 | RS_nRST | 3.3V | I_PU | RESET | Reset signal for Module | Connect to Reset Control PIN;Active low; There is an internal 24.9K pullup resistor
 | 16 | GND |  | G | GND | GND | Connect to GND
 | 17 | NC |  | NC | NC | No connection | Leave floating
 | 18 | GND |  | G | GND | GND | Connect to GND
 | 19 | VDD33 | 3.3V | P_IN | POWER | Digital Power Supply | Connect to Digital Power Supply:VDD33
 | 20 | GND |  | G | GND | GND | Connect to GND
 | 21 | VDD33 | 3.3V | P_IN | POWER | Digital Power Supply | Connect to Digital Power Supply:VDD33
 | 22 | VDD33 | 3.3V | P_IN | POWER | Digital Power Supply | Connect to Digital Power Supply:VDD33
 | 23 | VDD33 | 3.3V | P_IN | POWER | Digital Power Supply | Connect to Digital Power Supply:VDD33
 | 24 | RS_SPI_MOSI | 3.3V |  | Programming | Programming：MOSI | Leave floating
 | 25 | RS_SPI_SCK | 3.3V |  | Programming | Programming：SCK | Leave floating
 | 26 | RS_SPI_HOLD | 3.3V |  | Programming | Programming：HOLD | Leave floating
 | 27 | RS_SPI_WP | 3.3V |  | Programming | Programming：WP | Leave floating
 | 28 | RS_SPI_MISO | 3.3V |  | Programming | Programming：MISO | Leave floating
 | 29 | RS_SPI_CS | 3.3V |  | Programming | Programming：CS | Leave floating
 | 30 | GPIOOUT1 | 3.3V | I_PD/O | GPIO | Reserved GPIO：1 | Leave floating
 | 31 | GPIOOUT2 | 3.3V | I_PD/O | GPIO | Reserved GPIO：2 | Leave floating
 | 32 | GPIOOUT3 | 3.3V | I_PD/O | GPIO | Reserved GPIO：3 | Leave floating
 | 33 | TX0 | 3.3V | O_PU | UART | UART for debug：TXD | Connect to UART inerface:RXD; Leave floating if unused
 | 34 | RX0 | 3.3V | I_PU | UART | UART for debug：RXD | Connect to UART inerface:TXD; Leave floating if unused
Images | 35 | GND |  | G | GND | GND | Connect to GND
 | 36 | GND |  | G | GND | GND | Connect to GND
 | 37 | GND |  | G | GND | GND | Connect to GND
 | 38 | GND |  | G | GND | GND | Connect to GND
 | 39 | VDD50 | 5.0V | P_IN | POWER | Analog Power Supply | Connect to Analog Power Supply:VDD50
 | 40 | VDD50 | 5.0V | P_IN | POWER | Analog Power Supply | Connect to Analog Power Supply:VDD50
 | 41 | GND |  |  | Reinforcing metal fitting | Reinforcing metal fitting | Please Ignore!
 | 42 | GND |  |  | Reinforcing metal fitting | Reinforcing metal fitting | Please Ignore!
 | 43 | GND |  |  | Reinforcing metal fitting | Reinforcing metal fitting | Please Ignore!
 | 44 | GND |  |  | Reinforcing metal fitting | Reinforcing metal fitting | Please Ignore!

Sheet: Electrical Specifications
Power Specifications
Type | Description | Status | Voltage Requirement |  |  | Power Consumption |  |  | Power Supply Noise Requirement(Max)
 |  |  | Min | Type | Max | Min | Type | Max
VDD50 | Analog Power Supply for Sensor | Normal Operating | 4.5V | 5V | 5.5V | 4mA | 5mA | 23mA | 200uV(1Hz~50KHz)
VDD33 | Digital Power Supply | Normal Operating | 3.15V | 3.3V | 3.45V | 200mA | 220mA | 250mA | 50mV(1Hz~50KHz)
 |  | Opening Shutter | 3.15V | 3.3V | 3.45V | 300mA | 320mA | 350mA
DC and AC Electrical Specifications
Group | Description |  | MIN | TYPE | MAX | Notes
DVP IIC UART | High Level Output Voltage | VOH | 2.4V
 | Low Level Output Voltage | VOL |  |  | 0.4V
 | High Level Output Current | IOH | 4mA
 | Low Level Output Current | IOL | 4mA
 | TRI-STATE Output Current | IOZ |  |  | ±1uA
 | Pin Capacitance | CF
 | High Level Input Voltage | VIH | 2.0V |  | VDD33+0.3V
 | Low Level Input Voltage | VIL | -0.3V |  | 0.8V
 | Input Current | IL |  |  | ±1uA
 | Pull-up Resistor | RPU | 62kohm | 77kohm | 112kohm
 | Pull-down Resistor | RPD | 58kohm | 81kohm | 156kohm

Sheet: Notes
No. | I/O | Description | Notes
1 | I | Input signal
2 | I_PD | Input signal, internal pull-down
3 | I_PU | Input signal, internal pull-up
4 | O | Output signal
5 | O_OD | Output open drain (OD)
6 | O_PD | Output pull-down
7 | O_PU | Output pull-up
8 | I/O | Bidirectional (input/output) signal
9 | I_PD/O | Bidirectional signal, input pull-down
10 | I_PU/O | Bidirectional signal, input pull-up
11 | I_PD/OOD | Bidirectional signal, input pull-down and output OD
12 | I_PU/OOD | Bidirectional signal, input pull-up and output OD
13 | P_IN | Power supply input
14 | P_OUT | Power supply output
15 | G | Ground (GND)
16 | NC | No connection

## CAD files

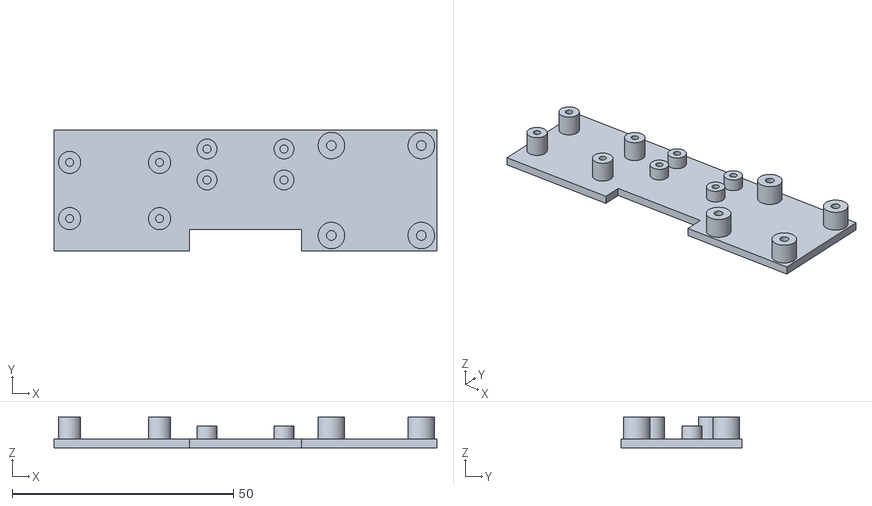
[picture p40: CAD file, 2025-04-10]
iCam/sensor_mount/tiny1c_proto_mount.stl
86.5 x 27.4 x 7.00

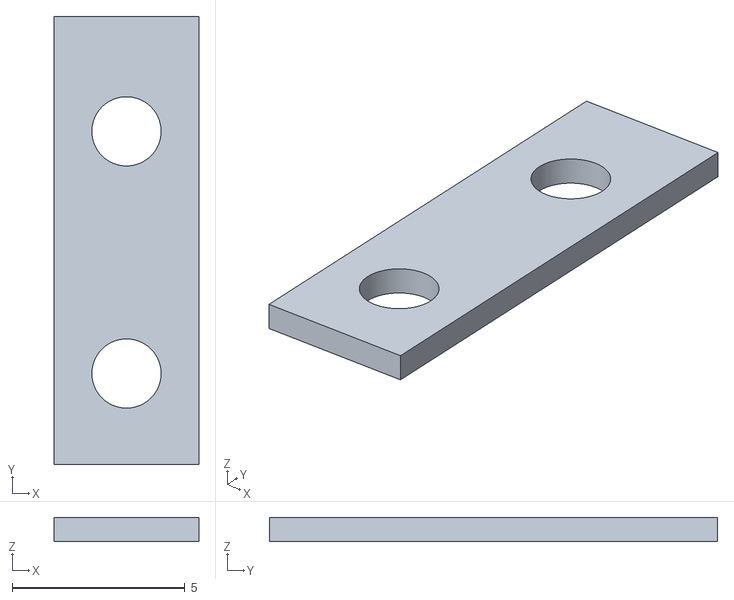
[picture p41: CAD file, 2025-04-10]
Tiny1C_breakout/spacer/tiny1c_breakout_spacer.stl
4.19 x 12.9 x 0.7

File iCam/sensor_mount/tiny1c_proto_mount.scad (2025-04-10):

//
// Prototype Tiny1C camera mounting plate.  Designed to be glued to
// a gCore enclosure.  Holds the Tiny1C breakout rev 2, an Adafruit
// VL53L4CX breakout and a Sparkfun Spark X AHT20 breakout.
//

//
// Base plate
//
base_w = 1 + 25.4 + 1 + 31.75 + 1 + 25.4 + 1;
base_l = 1 + 25.4 + 1;
base_h = 2.0;

//
// VL53L4CX breakout dimensions
//
vlc_delta_x = 20.32;
vlc_delta_y = 12.7;
vlc_offset_x = 1 + 2.54;
vlc_offset_y = (base_l - vlc_delta_y) / 2;
vlc_so_h = 5;
vlc_so_r = 2.5;
vlc_hole_r = 0.9;

//
// Tiny1C breakout
//
t1c_delta_x = 17.4;
t1c_delta_y = 7;
t1c_offset_x = (base_w - t1c_delta_x) / 2;
t1c_offset_y = base_l - 1 - 3.325 - t1c_delta_y;
t1c_so_h = 3;
t1c_so_r = 2.25;
t1c_hole_r = 0.9;

//
// AHT20 breakout
//
a20_delta_x = 20.32;
a20_delta_y = 20.32;
a20_offset_x = base_w - 1 - 2.54 - a20_delta_x;
a20_offset_y = 1 + 2.54;
a20_so_h = 5;
a20_so_r = 3;
a20_hole_r = 1.1;



module standoff(x, y, so_r, so_h, hole_r)
{
    translate([x, y, base_h - 0.1]) {
        difference() {
            cylinder(r=so_r, h=so_h + 0.1, $fn=120);
            
            cylinder(r=hole_r, h=so_h + 0.2, $fn=120);
        }
    }
}


module base_assy()
{
    // Base
    cube([base_w, base_l, base_h]);
    
    // VL53L4CX
    standoff(vlc_offset_x, vlc_offset_y, vlc_so_r, vlc_so_h, vlc_hole_r);
    standoff(vlc_offset_x+vlc_delta_x, vlc_offset_y, vlc_so_r, vlc_so_h, vlc_hole_r);
    standoff(vlc_offset_x, vlc_offset_y+vlc_delta_y, vlc_so_r, vlc_so_h, vlc_hole_r);
    standoff(vlc_offset_x+vlc_delta_x, vlc_offset_y+vlc_delta_y, vlc_so_r, vlc_so_h, vlc_hole_r);
    
    // Tiny1C
    standoff(t1c_offset_x, t1c_offset_y, t1c_so_r, t1c_so_h, t1c_hole_r);
    standoff(t1c_offset_x+t1c_delta_x, t1c_offset_y, t1c_so_r, t1c_so_h, t1c_hole_r);
    standoff(t1c_offset_x, t1c_offset_y+t1c_delta_y, t1c_so_r, t1c_so_h, t1c_hole_r);
    standoff(t1c_offset_x+t1c_delta_x, t1c_offset_y+t1c_delta_y, t1c_so_r, t1c_so_h, t1c_hole_r);
    
    // AHT20
    standoff(a20_offset_x, a20_offset_y, a20_so_r, a20_so_h, a20_hole_r);
    standoff(a20_offset_x+a20_delta_x, a20_offset_y, a20_so_r, a20_so_h, a20_hole_r);
    standoff(a20_offset_x, a20_offset_y+a20_delta_y, a20_so_r, a20_so_h, a20_hole_r);
    standoff(a20_offset_x+a20_delta_x, a20_offset_y+a20_delta_y, a20_so_r, a20_so_h, a20_hole_r);
}


difference()
{
    base_assy();
    
    translate([(base_w - 25.4)/2, -0.1, -0.1]) {
        cube([25.4, 5, base_h + 0.2]);
    }
}

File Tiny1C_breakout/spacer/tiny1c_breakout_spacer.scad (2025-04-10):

//
// Spacer for Infiray Tiny1C breakout board
//

difference()
{
    cube([4.19, 12.95, 0.7]);
    
    translate([(4.19/2), 2.63, -0.1]) {
        cylinder(r=1, h=1, $fn=120);
    }
    
    translate([(4.19/2), 9.63, -0.1]) {
        cylinder(r=1, h=1, $fn=120);
    }
}

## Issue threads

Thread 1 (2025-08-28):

Do you have a link to something like pcbway with a pre-assembled layout, etc?

matbeedotcom, 2025-08-28:
I'm trying to interface with my Tiny1C but their usb development board seems quite locked down

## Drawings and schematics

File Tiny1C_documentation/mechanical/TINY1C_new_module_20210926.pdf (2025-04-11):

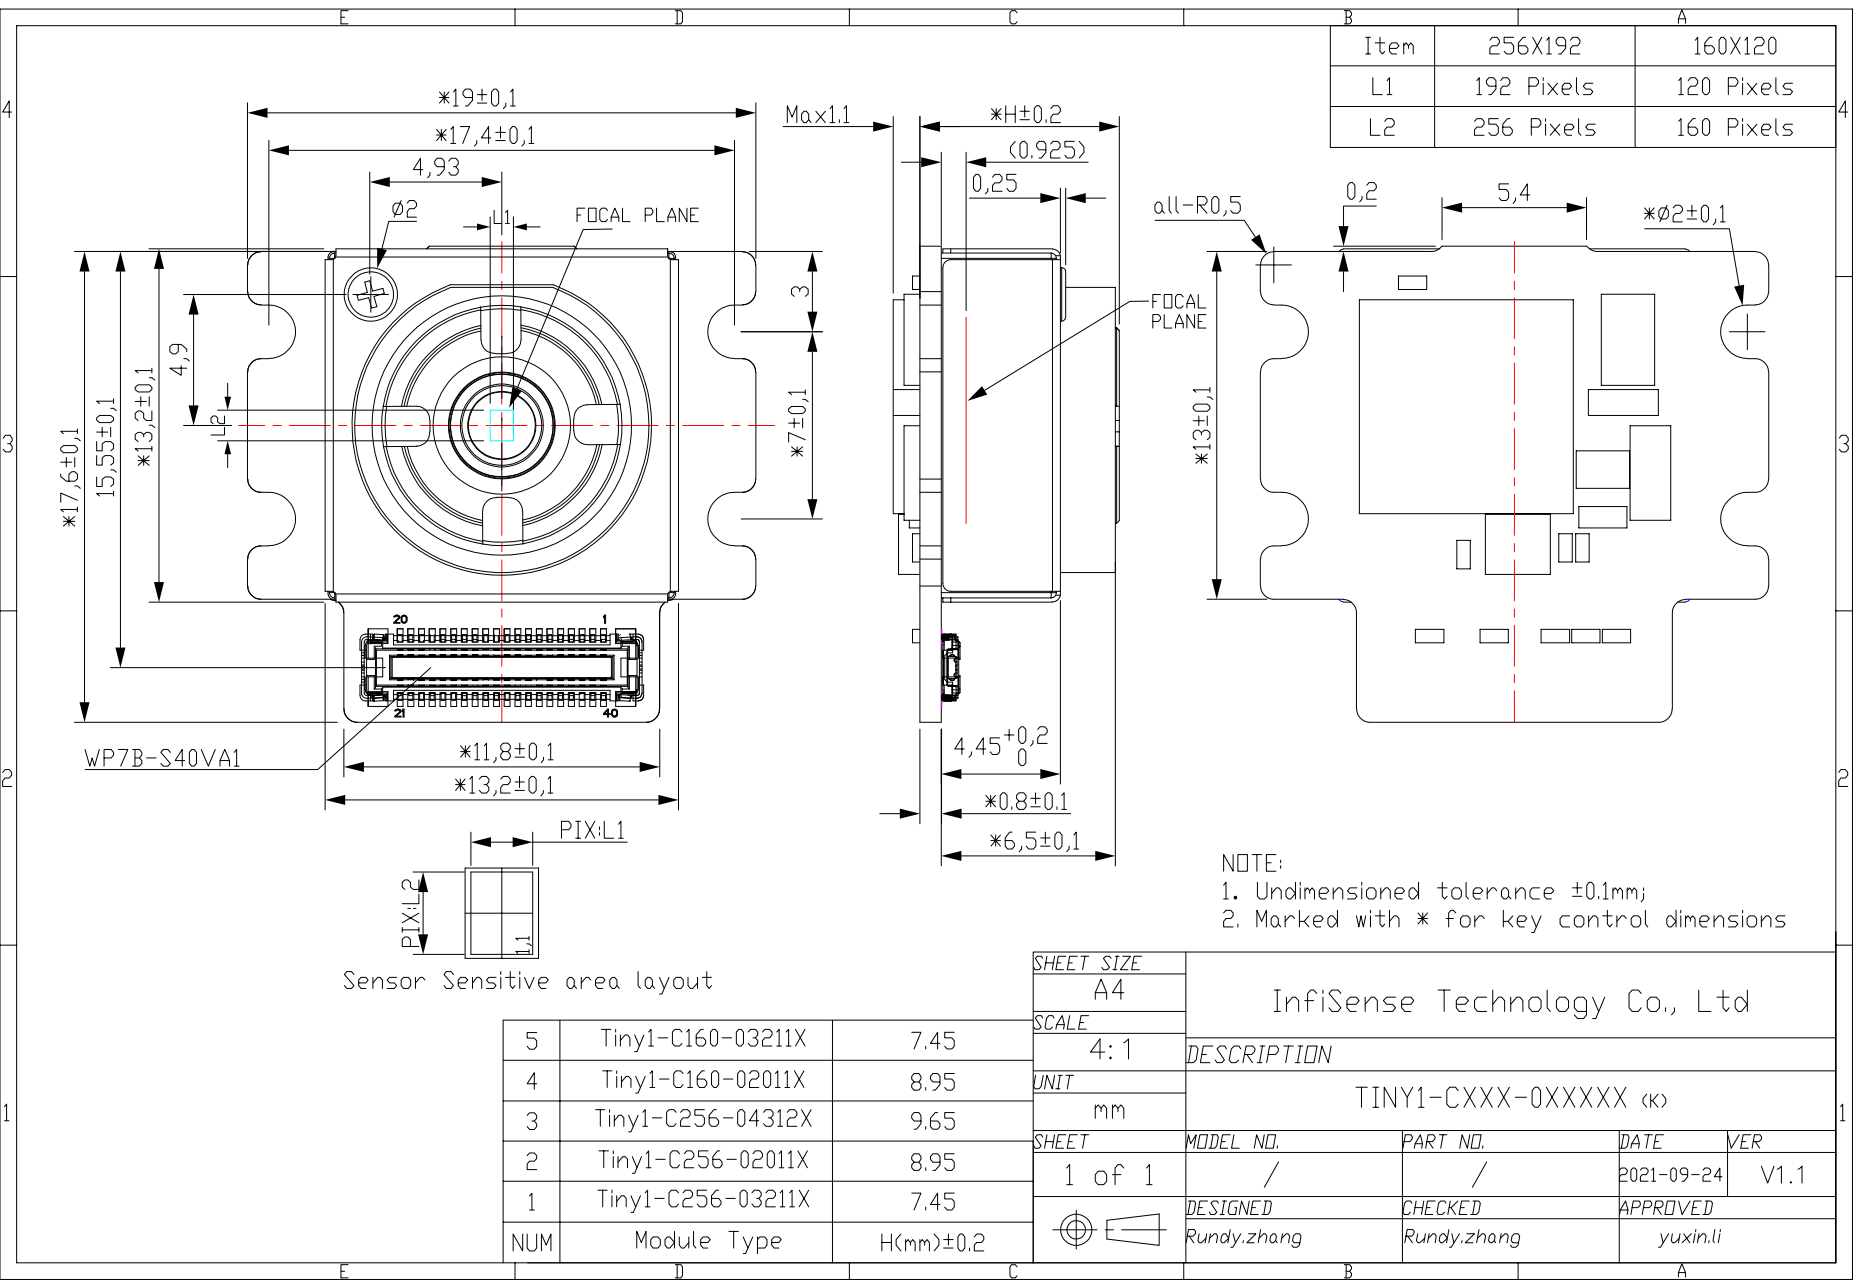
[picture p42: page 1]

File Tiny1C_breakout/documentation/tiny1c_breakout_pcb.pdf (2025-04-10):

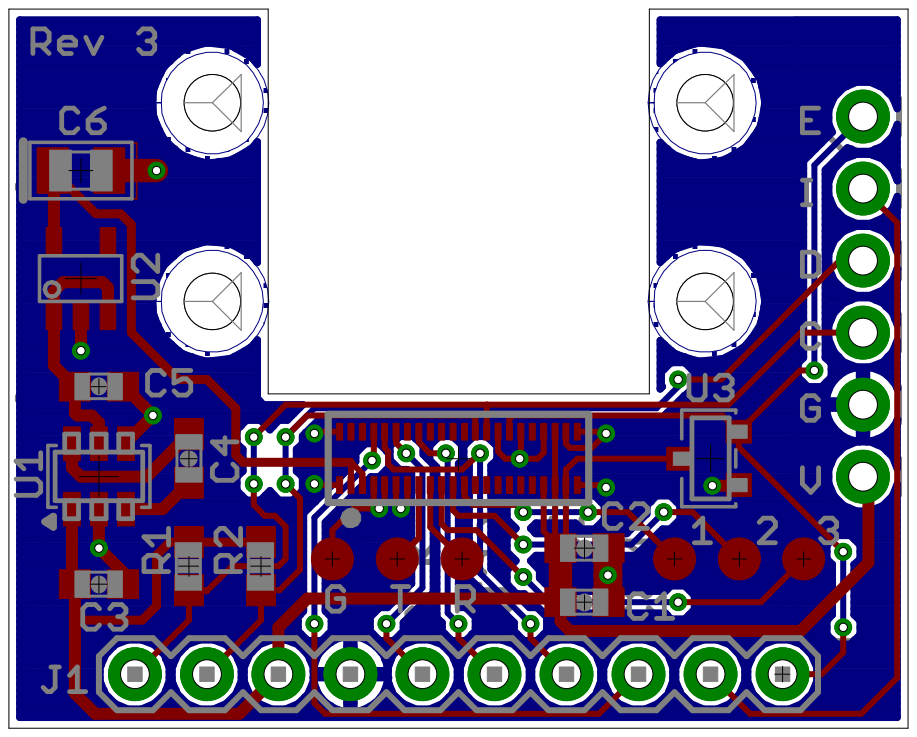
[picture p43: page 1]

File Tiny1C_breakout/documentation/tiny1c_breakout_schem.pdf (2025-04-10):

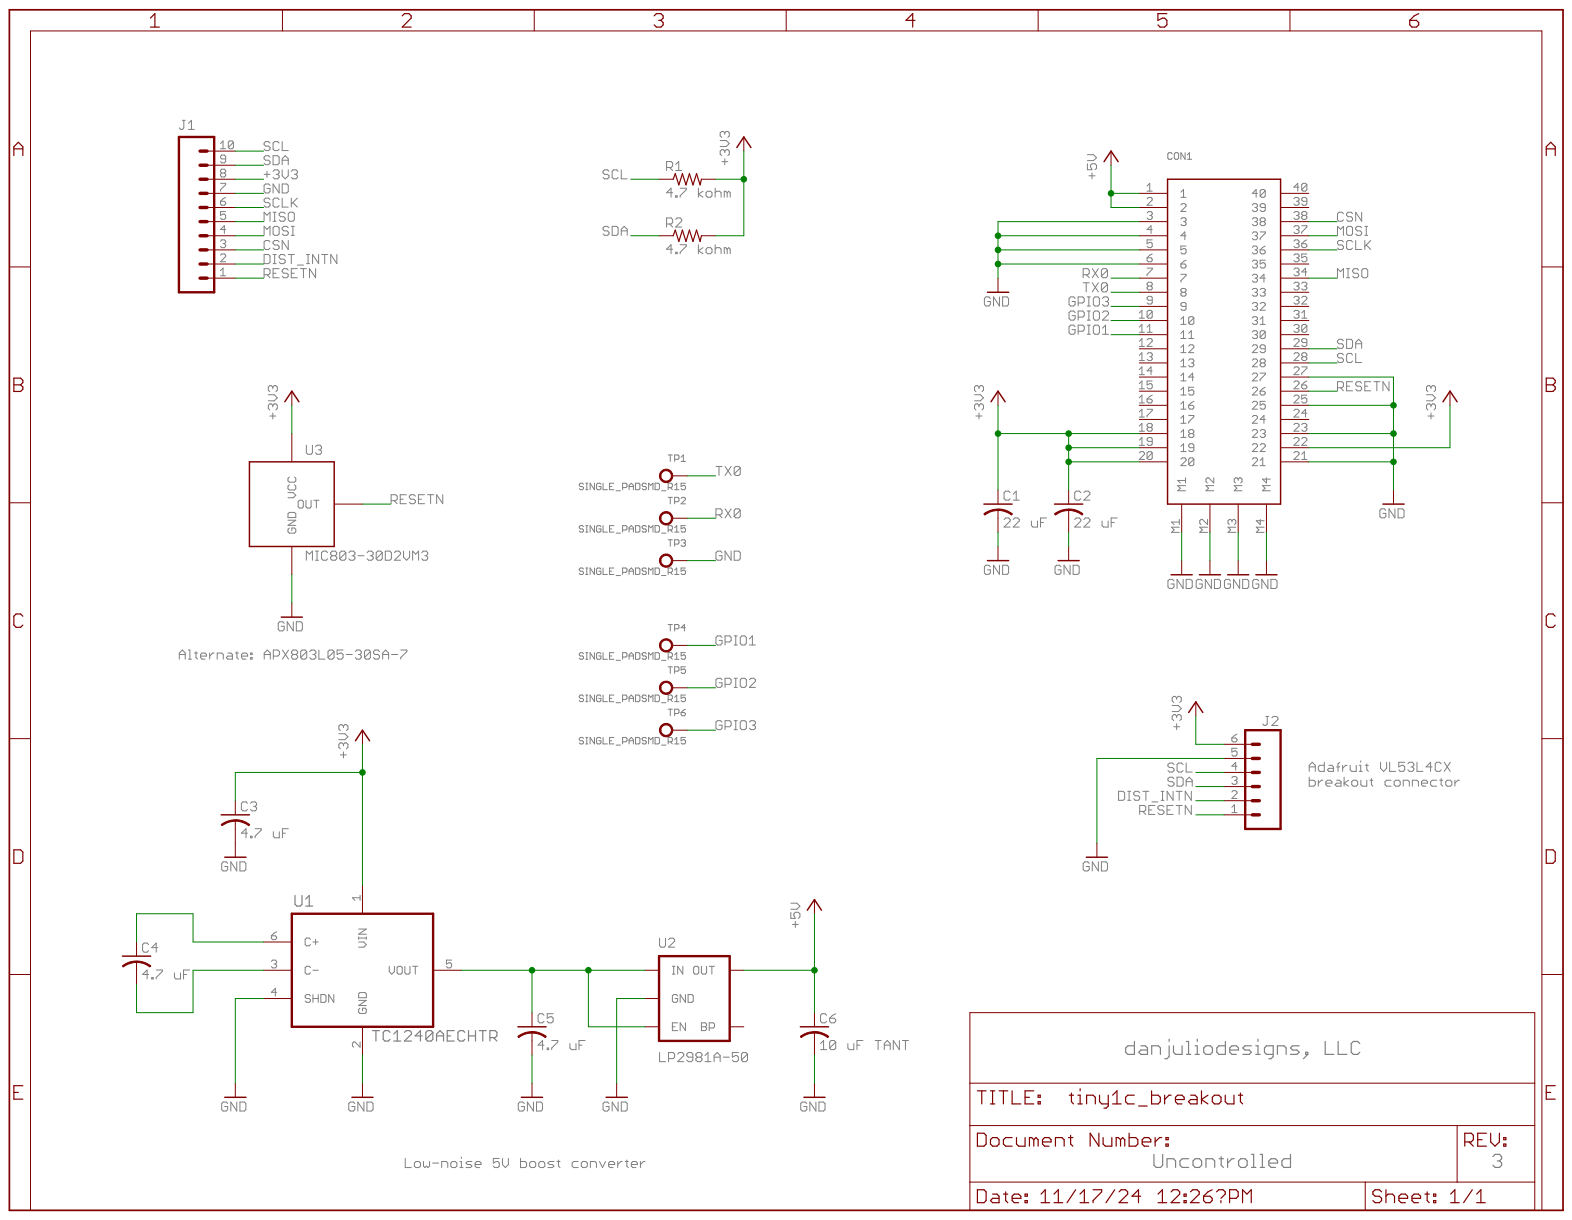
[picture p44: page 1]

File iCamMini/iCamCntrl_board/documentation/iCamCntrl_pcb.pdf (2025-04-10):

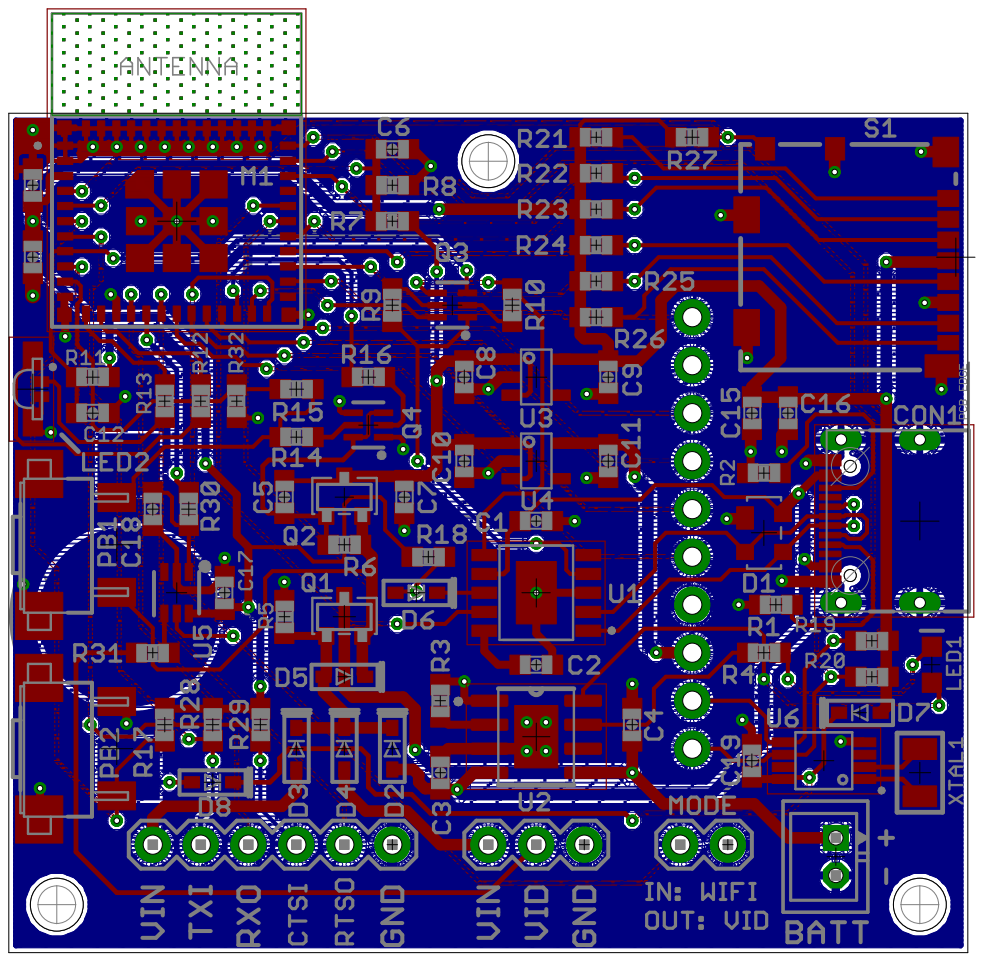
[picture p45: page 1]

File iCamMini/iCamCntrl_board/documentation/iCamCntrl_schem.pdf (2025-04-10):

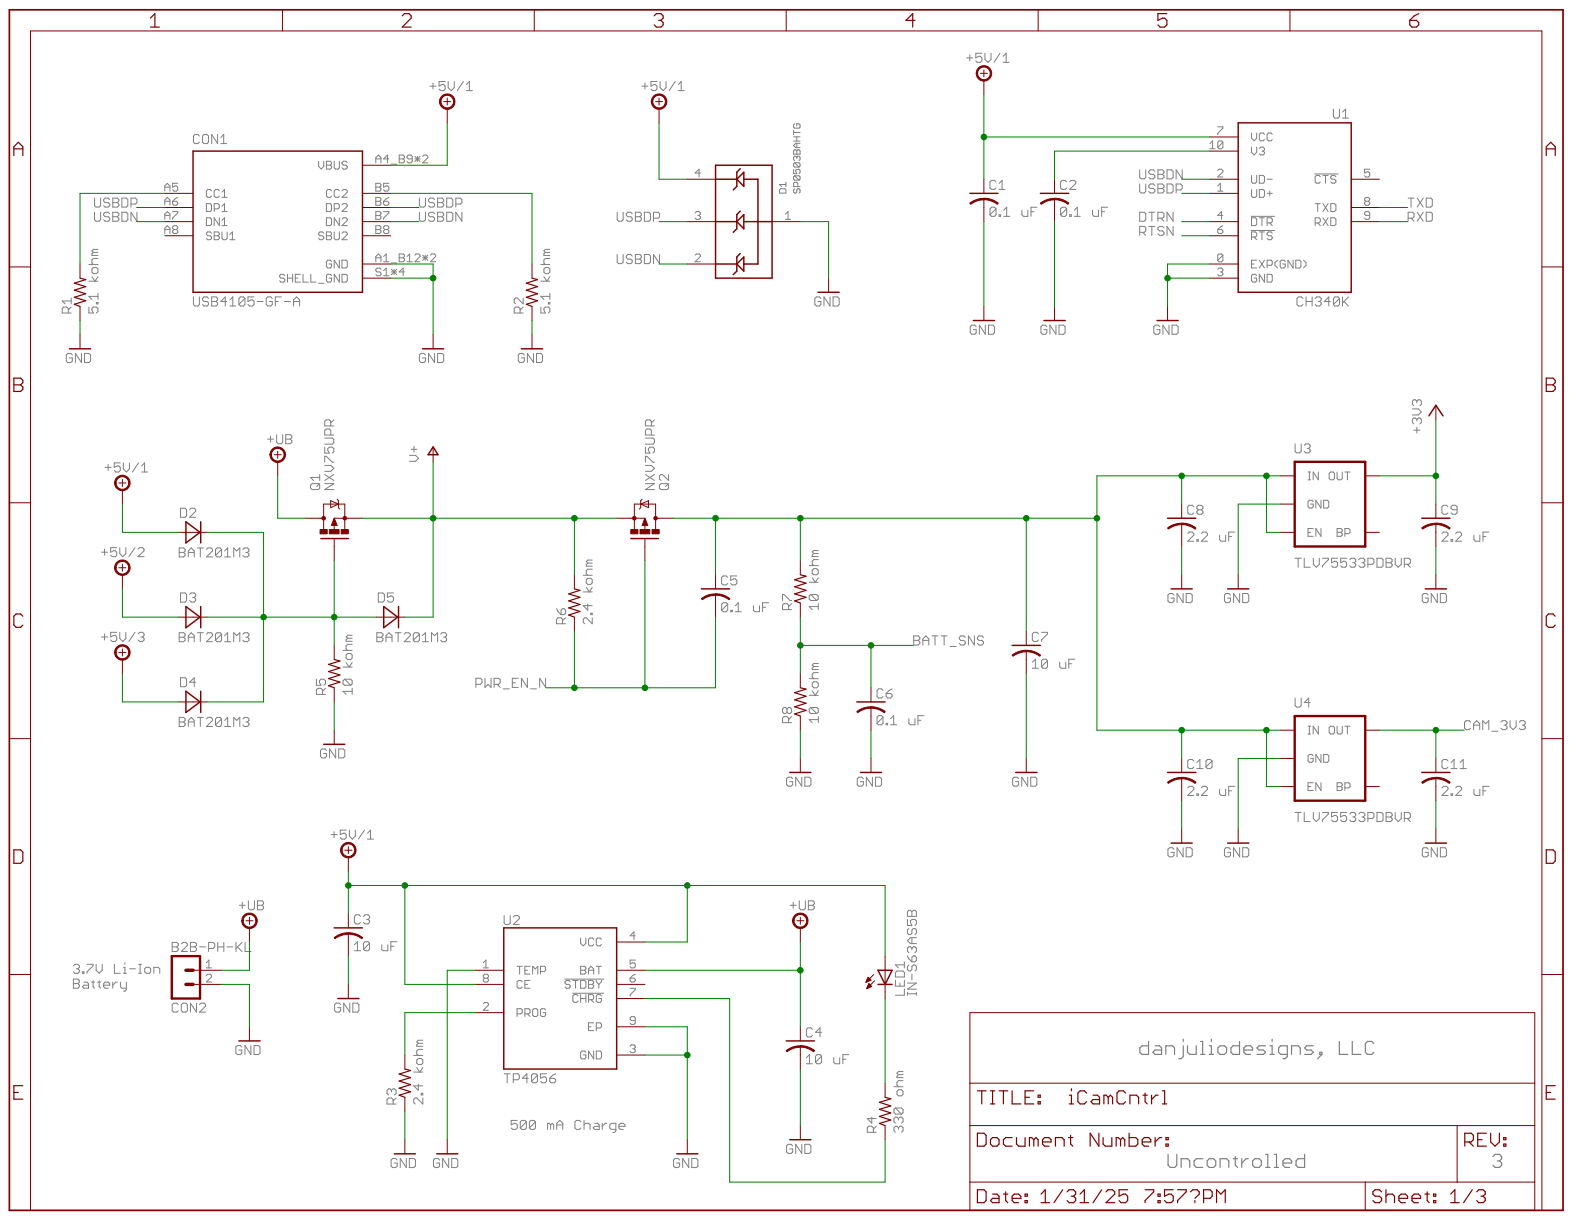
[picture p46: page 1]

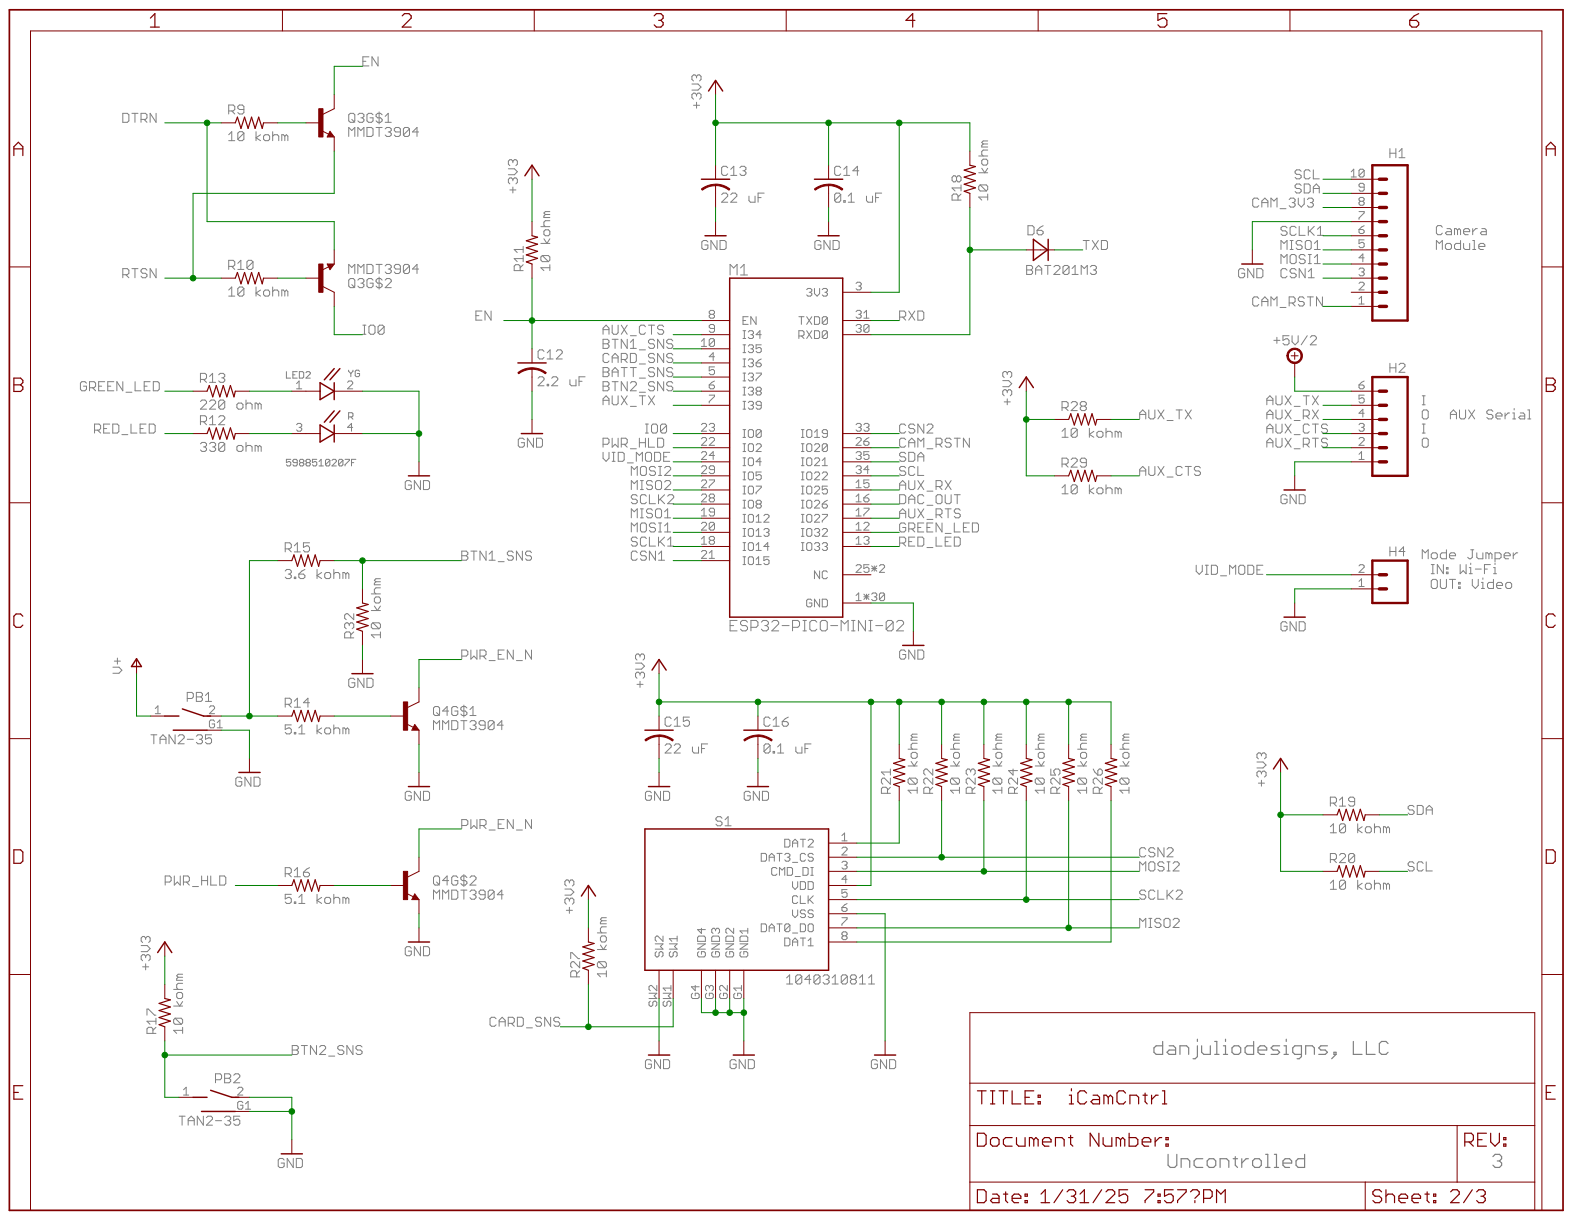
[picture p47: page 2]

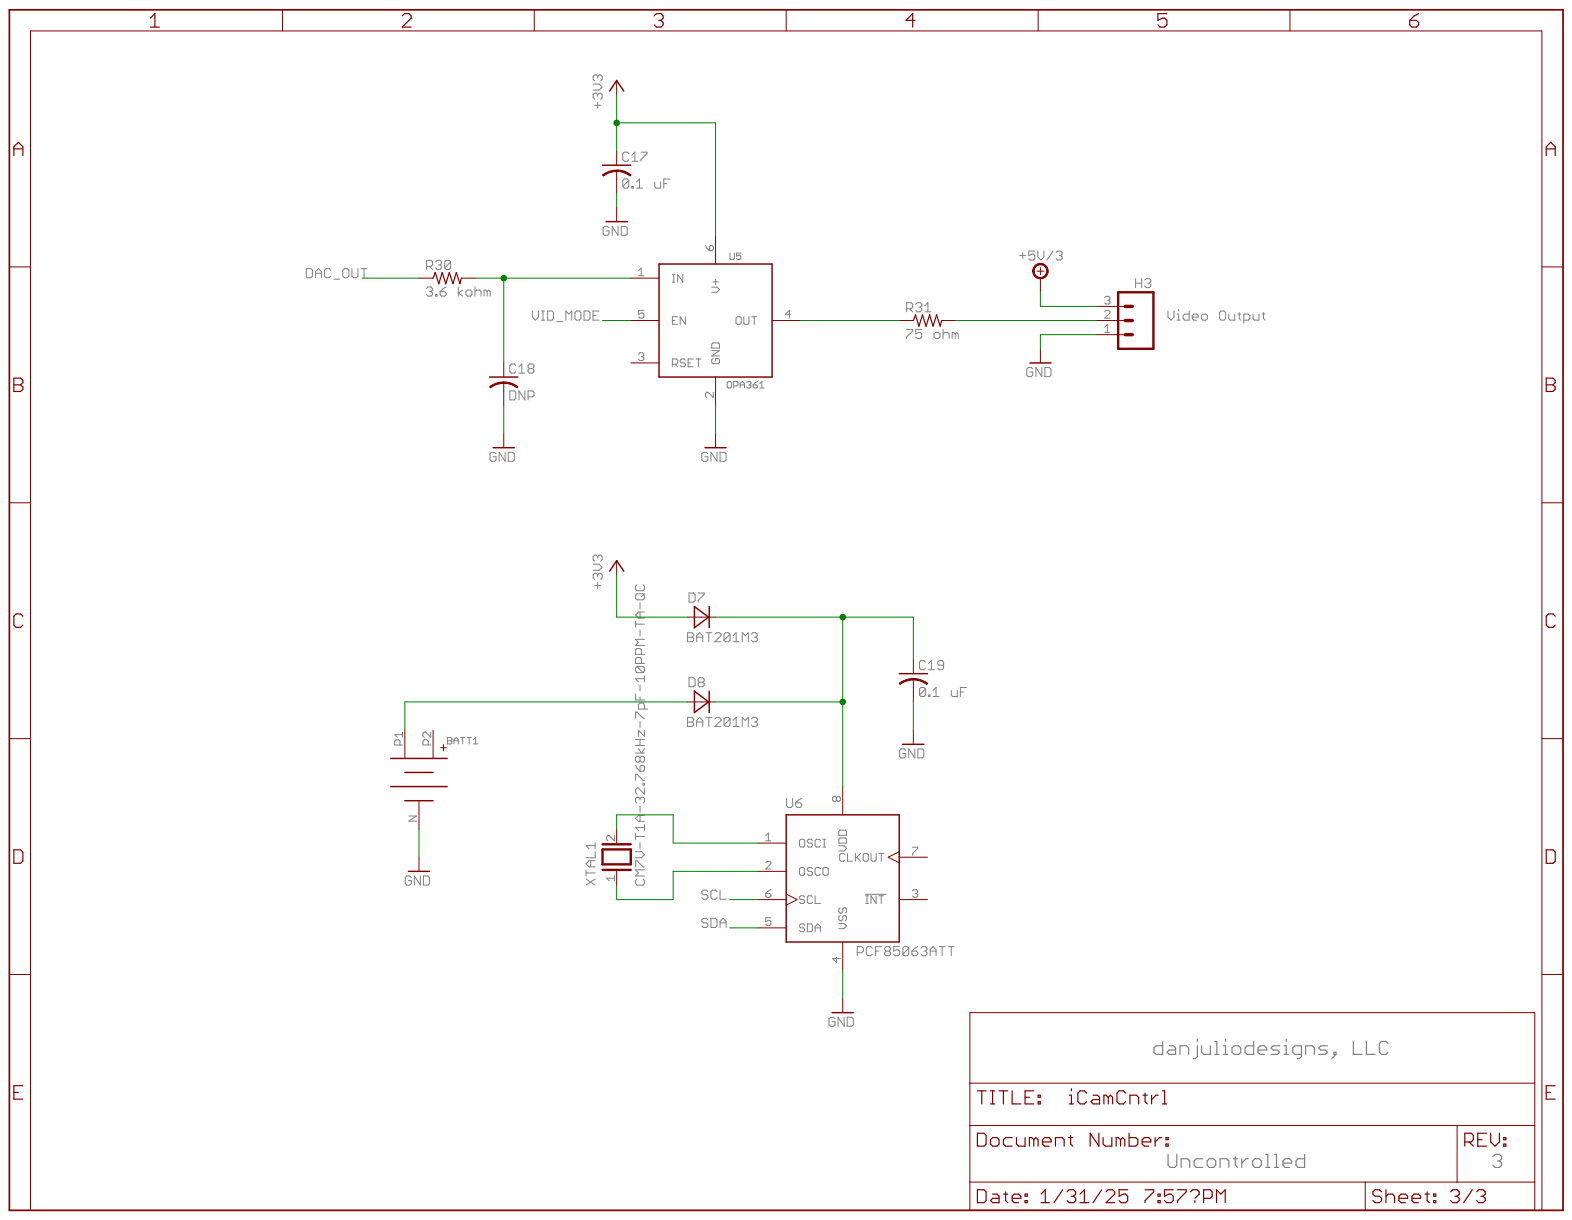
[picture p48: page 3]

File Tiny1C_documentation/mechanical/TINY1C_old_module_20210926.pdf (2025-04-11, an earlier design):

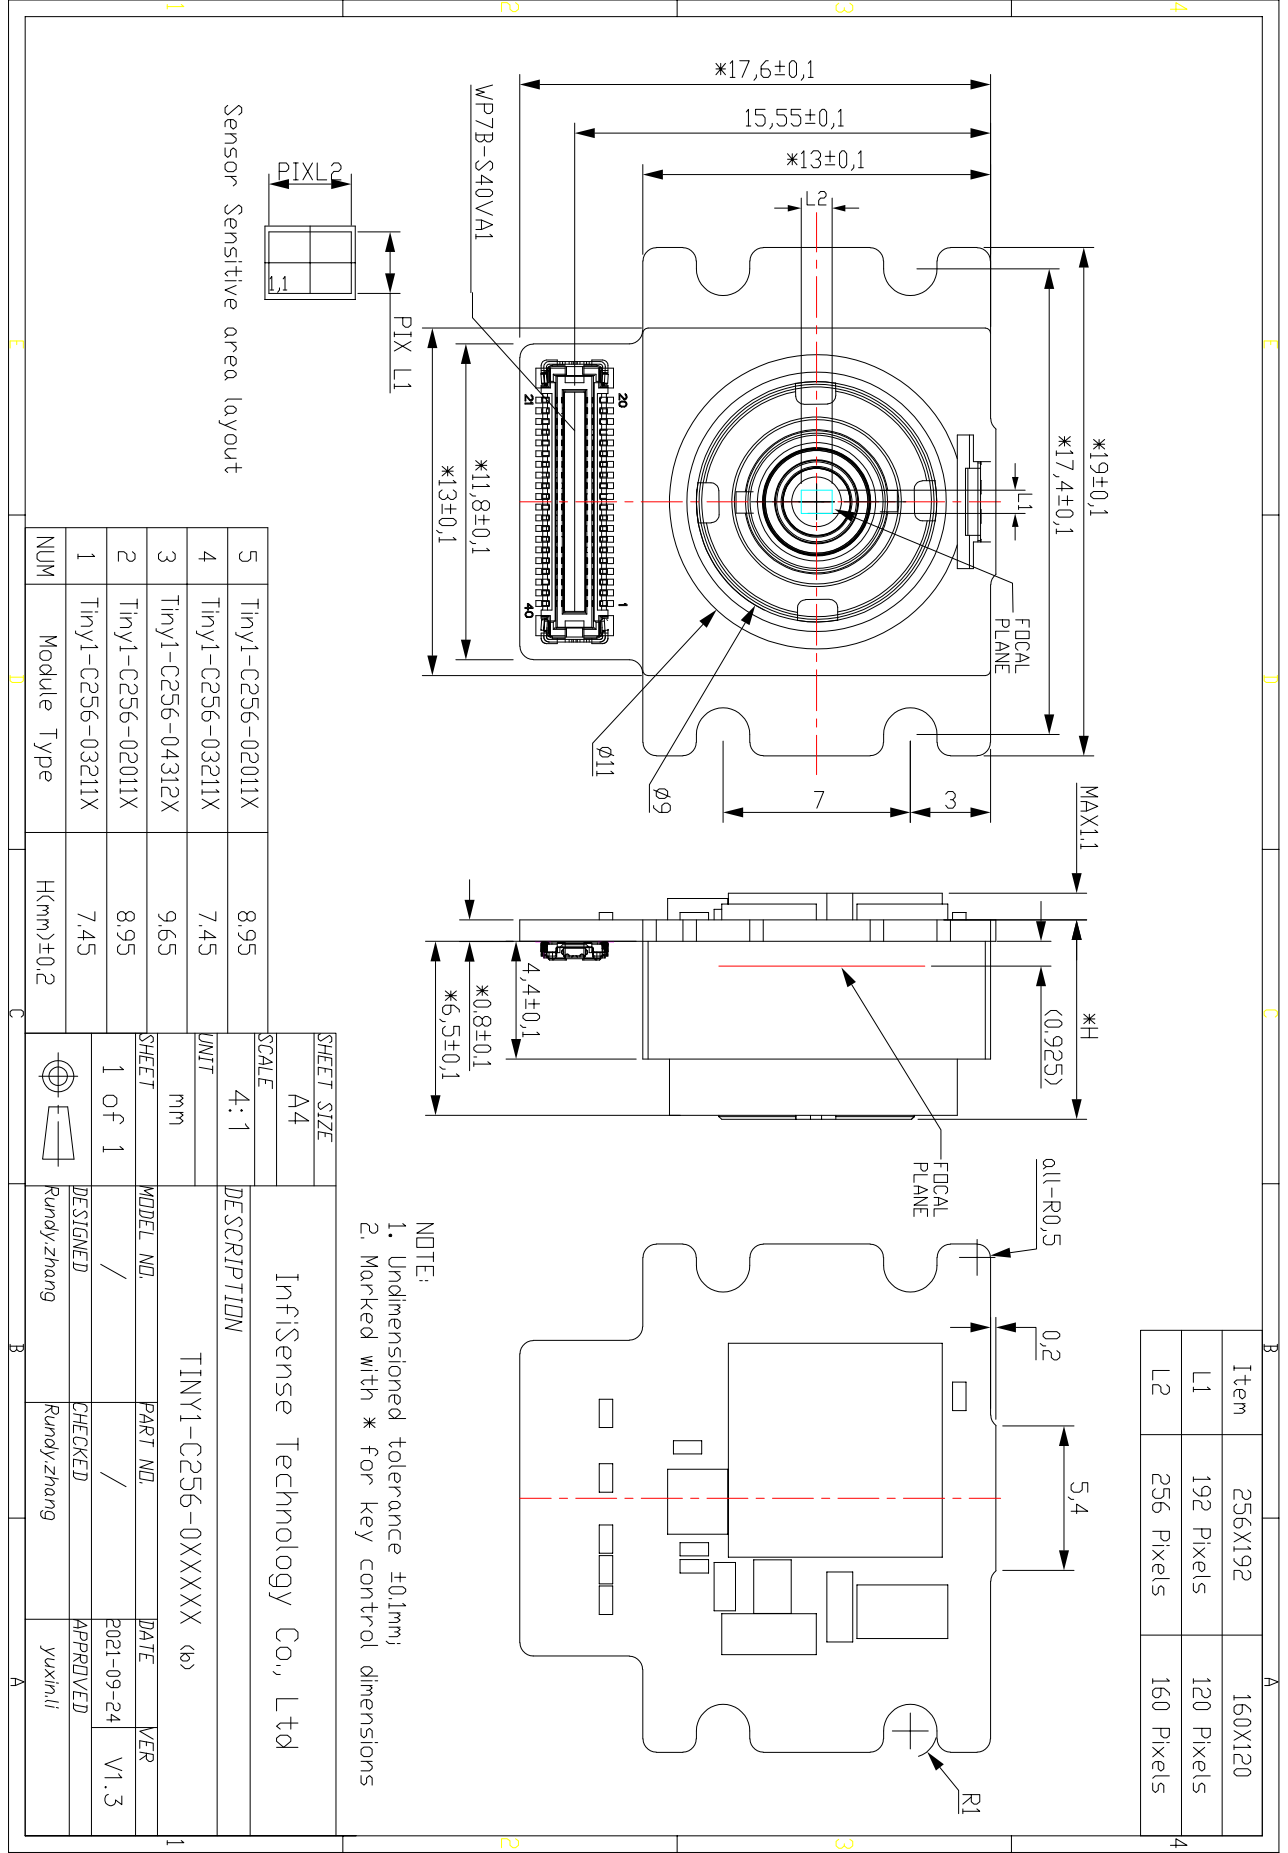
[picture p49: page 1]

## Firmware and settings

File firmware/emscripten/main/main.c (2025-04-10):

/*
 * iCamMini LVGL GUI component running in the browser using emscripten
 *
 * Copyright 2024 Dan Julio
 *
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
 * You should have received a copy of the GNU General Public License
 * along with this software.  If not, see <https://www.gnu.org/licenses/>.
 */
#include <stdint.h>
#include <stdbool.h>
#include <stdlib.h>
#include <unistd.h>
#define SDL_MAIN_HANDLED        /*To fix SDL's "undefined reference to WinMain" issue*/
#include <SDL2/SDL.h>
#include <emscripten.h>
#include <emscripten/em_js.h>
#include <emscripten/html5.h>
#include <emscripten/websocket.h>
#include "gui_main.h"
#include "lv_conf.h"
#include "lvgl/lvgl.h"
#include "lv_drivers/sdl/sdl.h"
#include "web_cmd_utilities.h"


//
// Global variables
//

// Browser information
static int browser_w;
static int browser_h;
static bool is_mobile_browser;

// Trigger to reconfigure GUI layout based on orientation changes
static bool reconfig_gui = false;

// Top-level LVGL objects
static lv_disp_t*    disp1;
static lv_indev_t*   mouse_indev;
static lv_indev_t*   kb_indev;
static lv_indev_t*   enc_indev;
static lv_obj_t*     screen;
static lv_task_t*    task_ws_trig;

// Websocket
 EMSCRIPTEN_WEBSOCKET_T ws;
 static bool websocket_open = false;
 


//
// Embedded javascript helpers
//
EM_JS(bool, isMobile, (), {
  return /Android|webOS|iPhone|iPad|iPod|BlackBerry|IEMobile|Opera Mini/i.test(navigator.userAgent);
});

EM_JS(int, get_browser_width, (), {
  return window.innerWidth;
});

EM_JS(int, get_browser_height, (), {
  return window.innerHeight;
});



//
// Forward declarations for internal functions
//
static EM_BOOL cb_orientation(int type, const EmscriptenOrientationChangeEvent* e, void* data);
static void do_loop(void *arg);
static void hal_init(void);
static void gui_init(void);
static void cb_ws_trig_timer(lv_task_t* t);
static void start_websocket();
static void stop_websocket();
static EM_BOOL onopen(int eventType, const EmscriptenWebSocketOpenEvent *websocketEvent, void *userData);
static EM_BOOL onmessage(int eventType, const EmscriptenWebSocketMessageEvent *websocketEvent, void *userData);
static EM_BOOL onerror(int eventType, const EmscriptenWebSocketErrorEvent *websocketEvent, void *userData);
static EM_BOOL onclose(int eventType, const EmscriptenWebSocketCloseEvent *websocketEvent, void *userData);



//
// Application entry point
//
int main()
{
	EMSCRIPTEN_RESULT res;
	
	printf("main start\n");
	
	// Get initial information about the browser we're running in
	browser_w = get_browser_width();
	browser_h = get_browser_height();
	is_mobile_browser = isMobile();
	// Set the canvas size to the one we are configuring LVGL for
	res = emscripten_set_canvas_element_size("#canvas", LV_HOR_RES_MAX, LV_VER_RES_MAX);
	if (res !=  EMSCRIPTEN_RESULT_SUCCESS) {
        printf("Unable to set canvas size - %d\n", res);
        // ??? what to do with this error - can it generate a pop-up error message? maybe not!
    }
    
	// Add a callback to detect mobile orientation changes
	res = emscripten_set_orientationchange_callback(NULL, EM_FALSE, cb_orientation);
    if (res !=  EMSCRIPTEN_RESULT_SUCCESS) {
        printf("Unable to add orientation callback - %d\n", res);
        // ??? what to do with this error - can it generate a pop-up error message?
    }
	
	// Initialize the websocket interface
    if (!web_cmd_init()) {
    	printf("Unable to initialize websocket command interface\n");
    	// ???
    }
    
    // Initialize LVGL
    lv_init();
    
    // Initialize the HAL (display, input devices, tick) for LVGL
    hal_init();
    
    // Initialize the GUI
    gui_init();
    
    // Setup the timer to initiate a websocket connection back to our server once we've handed control over to emscripten
	task_ws_trig = lv_task_create(cb_ws_trig_timer, 100, LV_TASK_PRIO_LOW, NULL);
	lv_task_set_repeat_count(task_ws_trig, 1);

	// Start the main emscripten loop
    emscripten_set_main_loop_arg(do_loop, NULL, -1, true);
    
    return 0;
}


EMSCRIPTEN_KEEPALIVE
void handleBrowserRefresh() {
	// Close any open socket to let the camera know we're going away
	if (websocket_open) {
		emscripten_websocket_close(ws, 1000, "Remote system initiated shutdown");
	}
}


EMSCRIPTEN_KEEPALIVE
void handleBrowserResize() {
	printf("Browser resize\n");
	
	reconfig_gui = true;
}



//
// Internal functions
//

static EM_BOOL cb_orientation(int type, const EmscriptenOrientationChangeEvent* e, void* data) {
    printf("Orientation (C) changed: type:%d, angle: %d\n", e->orientationIndex, e->orientationAngle);
    
    reconfig_gui = true;
    
    return EM_TRUE;
}


static void do_loop(void *arg)
{
	// Evaluate LVGL
    lv_task_handler();
    
    // Look for layout change
    if (reconfig_gui) {
    	reconfig_gui = false;
    	
    	// Update browser info
    	browser_w = get_browser_width();
		browser_h = get_browser_height();
		
		// Configure the GUI layout
		gui_main_reset_browser_dimensions(browser_w, browser_h);
    }
}


static void hal_init(void)
{
    sdl_init();

    // Create display buffers
    static lv_disp_buf_t disp_buf1;
    lv_color_t * buf1_1 = malloc(sizeof(lv_color_t) * LV_HOR_RES_MAX * LV_VER_RES_MAX);
    lv_color_t * buf1_2 = malloc(sizeof(lv_color_t) * LV_HOR_RES_MAX * LV_VER_RES_MAX);
    lv_disp_buf_init(&disp_buf1, buf1_1, buf1_2, LV_HOR_RES_MAX * LV_VER_RES_MAX);

    // Create the display
    static lv_disp_drv_t disp_drv;
    lv_disp_drv_init(&disp_drv);
    disp_drv.buffer = &disp_buf1;
    disp_drv.flush_cb = sdl_display_flush;
    disp_drv.hor_res = LV_HOR_RES_MAX;
    disp_drv.ver_res = LV_VER_RES_MAX;
    disp1 = lv_disp_drv_register(&disp_drv);

    // Add a mouse as input
    static lv_indev_drv_t indev_drv_1;
    lv_indev_drv_init(&indev_drv_1);
    indev_drv_1.type = LV_INDEV_TYPE_POINTER;
    indev_drv_1.read_cb = sdl_mouse_read;
    mouse_indev = lv_indev_drv_register(&indev_drv_1);

	// Add a keyboard as input
    static lv_indev_drv_t indev_drv_2;
    lv_indev_drv_init(&indev_drv_2);
    indev_drv_2.type = LV_INDEV_TYPE_KEYPAD;
    indev_drv_2.read_cb = sdl_keyboard_read;
    kb_indev = lv_indev_drv_register(&indev_drv_2);
    gui_keypad_group = lv_group_create();
/*    
    // Add a mousewheel as input
    static lv_indev_drv_t indev_drv_3;
    lv_indev_drv_init(&indev_drv_3);
    indev_drv_3.type = LV_INDEV_TYPE_ENCODER;
    indev_drv_3.read_cb = sdl_mousewheel_read;
    enc_indev = lv_indev_drv_register(&indev_drv_3);
    gui_encoder_group = lv_group_create();
*/
}


static void gui_init(void)
{
	// Get the top-level screen object to match the underlying web canvas since it is bigger
    // than the objects we'll render and we want a black background
	screen = lv_obj_create(NULL, NULL);
	lv_obj_set_pos(screen, 0, 0);
	lv_obj_set_size(screen, LV_HOR_RES_MAX, LV_VER_RES_MAX);
	lv_obj_set_style_local_bg_color(screen, LV_OBJ_PART_MAIN, LV_STATE_DEFAULT, LV_COLOR_MAKE(0x0,0x0,0x0));
	lv_obj_set_click(screen, false);
	
	// Initialize the GUI manager
	gui_main_init(screen, browser_w, browser_h, is_mobile_browser);
	gui_main_register_socket_connect(start_websocket);
	gui_main_register_socket_disconnect(stop_websocket);
	
	// Afer all LVGL objects have been created and devices desiring keypad/encoder input
	// have added themselves to the appropriate group, assign the groups to the input device
	lv_indev_set_group(kb_indev, gui_keypad_group);
//	lv_indev_set_group(enc_indev, gui_encoder_group);
	
	// Start the display
	lv_scr_load(screen);
}


static void cb_ws_trig_timer(lv_task_t* t)
{
	start_websocket();
}


static void start_websocket()
{
	char ws_url_string[80];
	
	// Upgrade to websocket
	sprintf(ws_url_string, "ws://%s/ws", emscripten_run_script_string("window.location.hostname"));
	printf("Attempt to upgrade: %s\n", ws_url_string);
	
	EmscriptenWebSocketCreateAttributes ws_attrs = {
        ws_url_string,
        NULL,
        EM_TRUE
    };
	ws = emscripten_websocket_new(&ws_attrs);
    
    emscripten_websocket_set_onopen_callback(ws, NULL, onopen);
    emscripten_websocket_set_onerror_callback(ws, NULL, onerror);
    emscripten_websocket_set_onclose_callback(ws, NULL, onclose);
    emscripten_websocket_set_onmessage_callback(ws, NULL, onmessage);
}


static void stop_websocket()
{
	// Close the websocket (normal closure - no longer needed)
	if (websocket_open) {
		emscripten_websocket_close(ws, 1000, "Remote system initiated shutdown");
	}
}


static EM_BOOL onopen(int eventType, const EmscriptenWebSocketOpenEvent *websocketEvent, void *userData)
{
	// Note socket open
	web_cmd_register_socket(websocketEvent->socket);
	gui_main_set_connected(true);
	websocket_open = true;
	
	return EM_TRUE;
}


static EM_BOOL onmessage(int eventType, const EmscriptenWebSocketMessageEvent *websocketEvent, void *userData)
{
	if (!websocketEvent->isText) {
		// Process this packet
		if (!web_cmd_process_socket_rx_data(websocketEvent->numBytes, websocketEvent->data)) {
			printf("web_cmd_process_socket_rx_data failed\n");
		}
	} else {
		printf("unexpected websocket text packet of %d bytes\n", websocketEvent->numBytes);
	}
	
	return true;
}


static EM_BOOL onerror(int eventType, const EmscriptenWebSocketErrorEvent *websocketEvent, void *userData)
{
	printf("onerror: %d\n", eventType);
	return EM_TRUE;
}


static EM_BOOL onclose(int eventType, const EmscriptenWebSocketCloseEvent *websocketEvent, void *userData)
{
	// Note socket closed
	printf("websocket closed: %s\n", websocketEvent->reason);
	web_cmd_register_socket(0);
	gui_main_set_connected(false);
	(void) emscripten_websocket_delete(websocketEvent->socket);
	websocket_open = false;
	return EM_TRUE;
}

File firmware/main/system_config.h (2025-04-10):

/*
 * System Configuration File
 *
 * Contains hardware-specific configuration and system configurable items.
 *
 * Copyright 2024 Dan Julio
 *
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
 * You should have received a copy of the GNU General Public License
 */
#ifndef SYSTEM_CONFIG_H
#define SYSTEM_CONFIG_H

#include "esp_system.h"



// ======================================================================================
// System debug
//

// Undefine to include the system monitoring task (included only for debugging/tuning)
//#define INCLUDE_SYS_MON



// ======================================================================================
// System hardware definitions
//

#ifdef CONFIG_BUILD_ICAM_MINI

//
// iCamMini IO Pins
//
#define BRD_OUT_MODE_IO        4

#define BRD_PWR_HOLD_IO        2

#define BRD_BATT_SNS_IO       37

#define BRD_BTN1_IO           35
#define BRD_BTN2_IO           38

#define BRD_GREEN_LED_IO      32
#define BRD_RED_LED_IO        33

#define BRD_SD_CSN_IO         19
#define BRD_SD_SCK_IO          8
#define BRD_SD_MOSI_IO         5
#define BRD_SD_MISO_IO         7
#define BRD_SD_SNS_IO         36

#define BRD_T1C_CSN_IO        15
#define BRD_T1C_SCK_IO        14
#define BRD_T1C_MOSI_IO       13
#define BRD_T1C_MISO_IO       12

#define BRD_SENSOR_RSTN_IO    20

#define BRD_I2C_SENSOR_SDA_IO 21
#define BRD_I2C_SENSOR_SCL_IO 22

#define BRD_AUX_TX_IO         25
#define BRD_AUX_RX_IO         39
#define BRD_AUX_RTS_IO        27
#define BRD_AUX_CTS_IO        34

#define BRD_VID_OUT_IO        26

#define BRD_DIAG_IO           0

// Unused but need to be defined
#define BRD_LCD_SCK_IO        -1
#define BRD_LCD_CSN_IO        -1
#define BRD_LCD_DC_IO         -1
#define BRD_LCD_MOSI_IO       -1

#define LCD_SPI_HOST    VSPI_HOST
#define LCD_DMA_NUM     1
#define LCD_SPI_FREQ_HZ 80000000


//
// iCamMini Hardware Configuration
//

// I2C
#define I2C_SENSOR_NUM     1
#define I2C_SENSOR_FREQ_HZ 400000

// SPI
//   Tiny1C uses HSPI
#define T1C_SPI_HOST    HSPI_HOST
#define T1C_DMA_NUM     1
#define T1C_SPI_FREQ_HZ 26670000

//   SD Card uses VSPI
#define SD_SPI_HOST     VSPI_HOST
#define SD_DMA_NUM      2
#define SD_SPI_FREQ_HZ  20000000

// Battery Monitor ADC input
#define BATT_SNS_SCALE_FACTOR 2

// ESP32 ADC Attenuation value to support maximum ADC input voltage
#define BATT_ADC_ATTEN        ADC_ATTEN_DB_12

// Approximate DC offset added to account for loss across switching transistors between
// battery and sense input (measured on prototype unit)
#define BATT_OFFSET_MV        20

// Filesystem utilities configuration
//  Using SPI
#define FILE_USE_SPI_IF
#define FILE_SDSPI_HOST         SD_SPI_HOST
#define FILE_SDSPI_DMA          SD_DMA_NUM
#define FILE_SDSPI_CS           BRD_SD_CSN_IO
#define FILE_SDSPI_CLK          BRD_SD_SCK_IO
#define FILE_SDSPI_MOSI         BRD_SD_MOSI_IO
#define FILE_SDSPI_MISO         BRD_SD_MISO_IO
#define FILE_SD_CLK_HZ          SD_SPI_FREQ_HZ

#else /* CONFIG_BUILD_ICAM_MINI */

//
// iCam IO Pins
//

#define BRD_LCD_SCK_IO        18
#define BRD_LCD_CSN_IO        5
#define BRD_LCD_DC_IO         27
#define BRD_LCD_MOSI_IO       23

#define BRD_T1C_CSN_IO        26
#define BRD_T1C_SCK_IO        25
#define BRD_T1C_MOSI_IO       0
#define BRD_T1C_MISO_IO       34

#define BRD_SENSOR_RSTN_IO    19

#define BRD_I2C_GCORE_SDA_IO  21
#define BRD_I2C_GCORE_SCL_IO  22
#define BRD_I2C_SENSOR_SDA_IO 33
#define BRD_I2C_SENSOR_SCL_IO 32

#define BRD_BTN1_IO           35
#define BRD_BTN2_IO           36


//
// iCam Hardware Configuration
//

// I2C Bus allocation
//  I2C Bus 1 - gCore on-board (EFM8 and FT6236 touchscreen controller)
//  I2C Bus 2 - Sensor bus (Tiny1C, distance, temp/humidity)
#define I2C_GCORE_NUM      0
#define I2C_GCORE_FREQ_HZ  100000
#define I2C_SENSOR_NUM     1
#define I2C_SENSOR_FREQ_HZ 400000

// SPI
//   LCD uses VSPI (no MISO)
//   Tiny1C uses HSPI
#define LCD_SPI_HOST    VSPI_HOST
#define LCD_DMA_NUM     1
#define LCD_SPI_FREQ_HZ 80000000
#define T1C_SPI_HOST    HSPI_HOST
#define T1C_DMA_NUM     2
#define T1C_SPI_FREQ_HZ 26670000

// Filesystem utilities configuration
//   Using SDMMC interface
#define FILE_SD_CLK_HZ  20000000

#endif /* CONFIG_BUILD_ICAM_MINI */



// ======================================================================================
// System configuration
//

// Battery state-of-charge curve for a pair of 2600 mAh 3.65 (3.7) volt batteries from
// BatterySpace (Powerizer 3.65V/5.2Ah) based on load testing with ~470 mA load
// and estimated 30 minute runtime before shutoff at 3.5V.
// (??? redo for something like 1000-1200 mAh battery)
//
#define BATT_75_THRESHOLD_MV    3890
#define BATT_50_THRESHOLD_MV    3700
#define BATT_25_THRESHOLD_MV    3580
#define BATT_0_THRESHOLD_MV     3525
#define BATT_CRIT_THRESHOLD_MV  3500

// Low battery indication interval
#define LOW_BATT_INDICATION_SEC 30

// Critical Battery Shutdown timeout
#define CRIT_BATTERY_OFF_SEC    30
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

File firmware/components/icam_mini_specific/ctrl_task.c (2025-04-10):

/*
 * Control Interface Task - Hardware management task for iCamMini.  Device-specific
 * functionality for monitoring the battery, controls, SD-card presence, video/web
 * jumper and controlling the Status LED.
 *
 * Copyright 2020-2024 Dan Julio
 *
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
 * You should have received a copy of the GNU General Public License
 * along with this program.  If not, see <https://www.gnu.org/licenses/>.
 */
#include "esp_system.h"
#ifdef CONFIG_BUILD_ICAM_MINI

#include <stdbool.h>
#include "ctrl_task.h"
#include "esp_log.h"
#include "esp_adc/adc_oneshot.h"
#include "esp_adc/adc_cali.h"
#include "esp_adc/adc_cali_scheme.h"
#include "driver/gpio.h"
#include "file_task.h"
#include "freertos/FreeRTOS.h"
#include "freertos/task.h"
#include "ps_utilities.h"
#include "sys_utilities.h"
#include "wifi_utilities.h"
#include "video_task.h"
#include "web_task.h"



//
// Control Task Constants
//

// Button indicies
#define CTRL_BTN_PWR 0
#define CTRL_BTN_AUX 1
#define CTRL_NUM_BTN 2

// LED Colors
#define CTRL_LED_OFF 0
#define CTRL_LED_RED 1
#define CTRL_LED_YEL 2
#define CTRL_LED_GRN 3

// LED State Machine states
#define CTRL_LED_ST_SOLID      0
#define CTRL_LED_ST_BLINK_ON   1
#define CTRL_LED_ST_BLINK_OFF  2
#define CTRL_LED_ST_RST_ON     3
#define CTRL_LED_ST_RST_OFF    4
#define CTRL_LED_ST_FLT_ON     5
#define CTRL_LED_ST_FLT_OFF    6
#define CTRL_LED_ST_FLT_IDLE   7
#define CTRL_LED_ST_FW_REQ_R   8
#define CTRL_LED_ST_FW_REQ_G   9
#define CTRL_LED_ST_FW_UPD_ON  10
#define CTRL_LED_ST_FW_UPD_OFF 11
#define CTRL_LED_ST_LB_OFF1    12
#define CTRL_LED_ST_LB_ON      13
#define CTRL_LED_ST_LB_OFF2    14
#define CTRL_LED_ST_SAVE_ON    15
#define CTRL_LED_ST_SAVE_OFF   16

// Control State Machine states
#define CTRL_ST_STARTUP            0
#define CTRL_ST_FAULT              1
#define CTRL_ST_VID                2
#define CTRL_ST_NET_NOT_CONNECTED  3
#define CTRL_ST_NET_CONNECTED      4
#define CTRL_ST_CLIENT_CONNECTED   5
#define CTRL_ST_RESET_ALERT        6
#define CTRL_ST_RESET_ACTION       7
#define CTRL_ST_RESTART_ALERT      8
#define CTRL_ST_RESTART_ACTION     9
#define CTRL_ST_FW_UPD_REQUEST     10
#define CTRL_ST_FW_UPD_PROCESS     11
#define CTRL_ST_WAIT_OFF           12

// Battery averaging array size
#define CTRL_BATT_ARRAY_LEN        10

//
// GPIO to ADC1 Channel mapping
//
static const int gpio_2_adc1_ch[40] = {
	-1, -1, -1, -1, -1, -1, -1, -1, -1, -1,
	-1, -1, -1, -1, -1, -1, -1, -1, -1, -1,
	-1, -1, -1, -1, -1, -1, -1, -1, -1, -1,
	-1, -1,  4,  5,  6,  7,  0,  1,  2,  3
};



//
// Control Task variables
//
static const char* TAG = "ctrl_task";

// Board/IO related
static bool sd_present = false;
static int ctrl_output_format;

// Batt/ADC related
static int batt_channel;
static adc_cali_handle_t cali_handle;
static adc_oneshot_unit_handle_t adc1_handle;
static int batt_read_timer;
static int batt_low_indication_timer;
static int batt_crit_shutdown_timer;
static uint16_t batt_avg_array[CTRL_BATT_ARRAY_LEN];
static uint16_t ctrl_batt_mv;

// State
static int ctrl_state;
static int ctrl_pre_activity_state;              // ctrl_state to return to from fault
static int ctrl_led_state;
static int ctrl_led_ret_state;                   // ctrl_led_state to return to from low-battery or file save blink(s)
static int ctrl_action_timer;
static int ctrl_led_timer;
static int ctrl_fault_led_count;
static int ctrl_fault_type = CTRL_FAULT_NONE;

// Incoming Notifications
static bool notify_startup_done = false;
static bool save_notification_success = false;

// Mode dependent notifications
static TaskHandle_t output_task;
static uint32_t task_crit_batt_notification;
static uint32_t task_shutdown_notification;



//
// Forward Declarations for internal functions
//
static void ctrl_task_init();
static void ctrl_debounce_pwr_button(bool* short_p, bool* long_p, bool* down);
static void ctrl_debounce_aux_button(bool* short_p, bool* long_p, bool* down);
static void ctrl_debounce_sd_input(bool* present);
static void ctrl_eval_batt();
static uint16_t ctrl_read_batt_mv();
static uint16_t ctrl_get_new_batt_avg_mv(uint16_t cur_reading);
static void ctrl_set_led(int color);
static void ctrl_eval_sd_present();
static void ctrl_eval_sm();
static void ctrl_set_state(int new_st);
static void ctrl_eval_led_sm();
static void ctrl_set_led_state(int new_st);
static void ctrl_handle_notifications();
static void ctrl_setup_output_notifications();



//
// API
//
void ctrl_task()
{
	ESP_LOGI(TAG, "Start task");
	
	ctrl_task_init();
	
	while (1) {
		vTaskDelay(pdMS_TO_TICKS(CTRL_EVAL_MSEC));
		ctrl_handle_notifications();
		ctrl_eval_led_sm();
		ctrl_eval_sm();
		
		// Evaluate notification generating tasks only after the system is up (all
		// other tasks are running)
		if (notify_startup_done) {
			ctrl_eval_batt();
			ctrl_eval_sd_present();
		}
	}
}


int ctrl_get_output_mode()
{
	return ctrl_output_format;
}


// Not protected by semaphore since it won't be accessed until after subsequent notification
void ctrl_set_fault_type(int f)
{	
	if (f == CTRL_FAULT_NONE) {
		// Asynchronously notify this task to return to the previous state
		ctrl_fault_type = f;
		xTaskNotify(task_handle_ctrl, CTRL_NOTIFY_FAULT_CLEAR, eSetBits);
	} else {
		if (ctrl_state != CTRL_ST_FAULT) {
			// Asynchronously notify this task only for the first fault
			ctrl_fault_type = f;
			xTaskNotify(task_handle_ctrl, CTRL_NOTIFY_FAULT, eSetBits);
		}	
	}
}


// Called before sending CTRL_NOTIFY_SAVE_START
void ctrl_set_save_success(bool s)
{
	save_notification_success = s;
}


uint16_t ctrl_get_batt_mv()
{
	return ctrl_batt_mv;
}


int ctrl_get_batt_percent()
{
	uint16_t local_mv = ctrl_batt_mv;
	
	if (local_mv < BATT_0_THRESHOLD_MV) {
		return 0;
	} else if (local_mv < BATT_25_THRESHOLD_MV) {
		return 25;
	} else if (local_mv < BATT_50_THRESHOLD_MV) {
		return 50;
	} else if (local_mv < BATT_75_THRESHOLD_MV) {
		return 75;
	} else {
		return 100;
	}
}


bool ctrl_get_sdcard_present()
{
	return sd_present;
}
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

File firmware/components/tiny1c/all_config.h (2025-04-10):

/*
 * Originally part of Infiray "ASIC_2121W_RTOS_SDK_V1.0.0_release".
 * Modified by Dan Julio for use in iCam/iCamMini.
 */
#pragma once

#define		FALCON_CMD
#define I2C_TRANSFER_WAIT_TIME_MS  20000
/**
 * @brief Return error's type
 */
typedef enum{
	/// success
	IR_SUCCESS						= 0,
	/// parameters error
	IR_ERROR_PARAM					= -1,
	/// libiruvc's service context initialize failed
	IR_UVC_INIT_FAIL				= -2,
	/// get device list failed
	IR_GET_DEVICE_LIST_FAIL			= -3,
	/// find device via pid/vid/name failed
	IR_FIND_DEVICE_FAIL				= -4,
	/// find device via pid/vid/name failed
	IR_NOT_GET_DEVICE_INFO			= -5,
	/// open device fail
	IR_DEVICE_OPEN_FAIL				= -6,
	/// get device's descriptor failed
	IR_GET_DEVICE_DESCRIPTOR_FAIL	= -7,
	/// device already opened
	IR_DEVICE_OPENED				= -8,
	/// device doesn't provide a matching stream
	IR_GET_FORMAT_FAIL				= -9,
	/// user's callback fucntion is empty
	IR_USER_CALLBACK_EMPTY			= -10,
	/// device start streaming failed
	IR_START_STREAMING_FAIL			= -11,
	/// over time when getting frame
	IR_GET_FRAME_OVER_TIME			= -12,
	/// vdcmd not registered
	IR_VDCMD_NOT_REGISTER			= -13,
	/// vdcmd register failed
	IR_VDCMD_REGISTER_FAIL			= -14,
	/// control transter failed
	IR_CONTROL_TRANSFER_FAIL		= -15,
	/// checking vdcmd send failed
	IR_CHECK_DONE_FAIL				= -16,
	/// vdcmd's length is too long
	IR_VDCMD_TOO_LONG				= -17,
	/// reset device fail
	IR_RESET_DEVICE_FAIL			= -18,
	/// clear halt fail
	IR_CLEAR_HALT_FAIL				= -19,
	/// unsupported command
	IR_UNSUPPORTED_CMD				= -20,
	/// i2c transfer fail
	IR_I2C_TRANSFER_FAIL			= -21,
	/// i2c device open fail
	IR_I2C_DEVICE_OPEN_FAIL			= -22,
	/// i2c get register fail
	IR_I2C_GET_REGISTER_FAIL		= -23,
	/// i2c set register fail
	IR_I2C_SET_REGISTER_FAIL		= -24,
	/// memory allocation fail
	IR_MEM_ALLOC_FAIL				= -25
}ir_error_t;

/**
 * @brief Log message levels
 */
typedef enum{
	/// all debug&error infomation
	IR_LOG_DEBUG						= 0,
	/// all error infomation
	IR_LOG_ERROR						= 1,
	/// no print infomation(default)
	IR_LOG_NO_PRINT					= 2
}ir_log_level_t;

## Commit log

2025-04-10 Initial checkin
    [partitions.csv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]
2025-04-11 Added Tiny1C documentation
    [TINY1C项目_硬件接口资料_V1.1.xlsx]
2025-11-26 Added Mouser BOM link and centroid file for TIny1C Breakout
    [tiny1c_breakout_centroid.csv]

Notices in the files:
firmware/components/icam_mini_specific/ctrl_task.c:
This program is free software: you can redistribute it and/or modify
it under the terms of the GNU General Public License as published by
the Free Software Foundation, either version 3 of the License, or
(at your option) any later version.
